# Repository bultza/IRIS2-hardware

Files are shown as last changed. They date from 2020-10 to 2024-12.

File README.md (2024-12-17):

# IRIS-2 Hardware
IRIS-2 is a 5 kg video and imaging instrument built by a group of friends (formed by enthusiastic amateur astronomers, engineers, and technicians). It follows the legacy of IRIS-1, which flew on Sunrise II in 2013. Its main goal is to provide imagery for communication and outreach, while also assisting in monitoring and improving the mechanical interfaces and PCS of the [Sunrise III observatory](https://www.mps.mpg.de/solar-physics/sunrise) from launch through landing and recovery. The cameras record 4K, 30 fps video for 2 hours during launch, 1 hour during landing, and 15 minutes at 120 fps during balloon release. At other times, they capture stills at 120-second intervals for time-lapse creation.

IRIS-2 was designed and assembled by:
* [Ramón García](https://github.com/rgalarcia/)
* [Miguel Angel Gomez](https://x.com/haploretro)
* [David Mayo](https://github.com/dmay0/)
* [Aitor Conde](https://github.com/bultza/)

To know more about the [Sunrise solar observatory](https://www.mps.mpg.de/solar-physics/sunrise)

## Design
IRIS-2 is build around 4 battery-less GOPRO Hero 4 cameras, with a central computer build with a MSP430 FRAM based microcontroller. The Instrument should be:
* Power independant
* Fully autonomous to detect launch and landing
* Able to make 4K videos
* Able to make a full timelapse of the flight of Sunrise over 7 day
* Able to stay in standby for days while drawing as less energy as possible.

## The hardware
The hardware has been designed using Altium Designer 21. The instrument has 2 boards (CPU and interface board), 4 cameras and a battery pack:
* The [IRIS2_PCB_CPU](https://github.com/bultza/IRIS2-hardware/tree/main/IRIS2_PCB_CPU): Where all the magic happens.
* The [IRIS2_PCB_Frontplate](https://github.com/bultza/IRIS2-hardware/tree/main/IRIS2_PCB_FrontPlate): a PCB to interface the instrument with the exterior world.
* 4 "GoPro HERO 4" cameras
* 4 [MewPro 2](https://mewpro.cc/en/product/mewpro-2/) interface boards to control the cameras
* 56 NiMH Eneloop AA cells, (8 in parallel, 7 in series)

<div align="center">
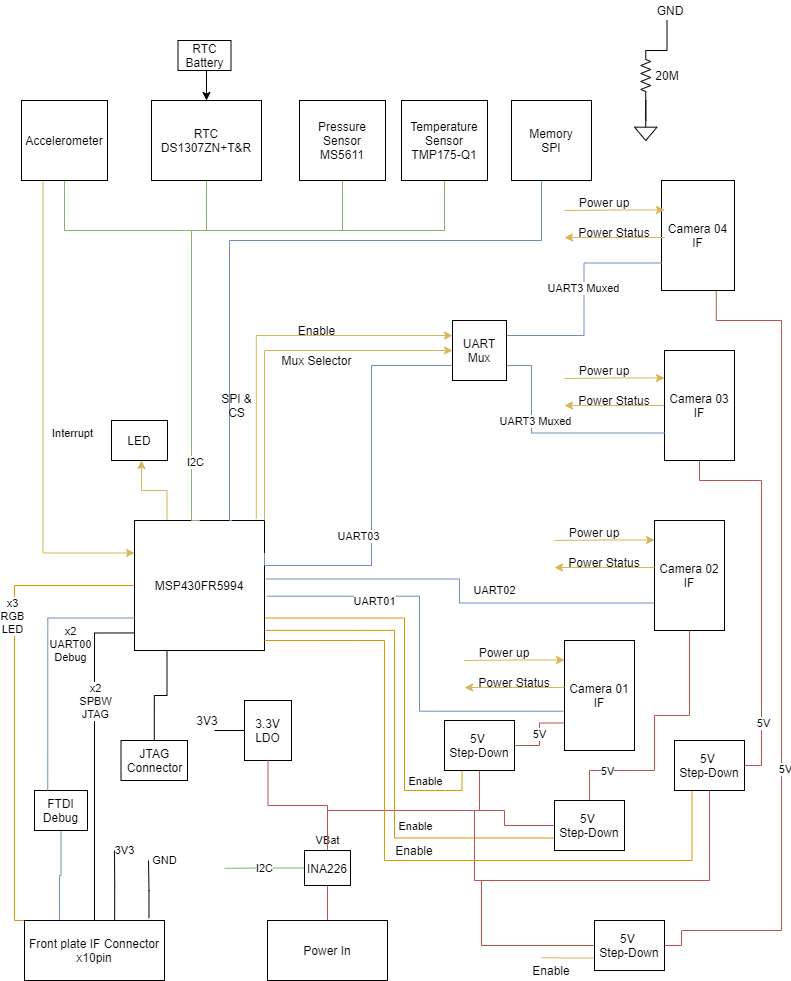
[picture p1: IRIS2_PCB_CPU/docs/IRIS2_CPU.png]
IRIS2 CPU Block Diagram

</div>

<div align="center">
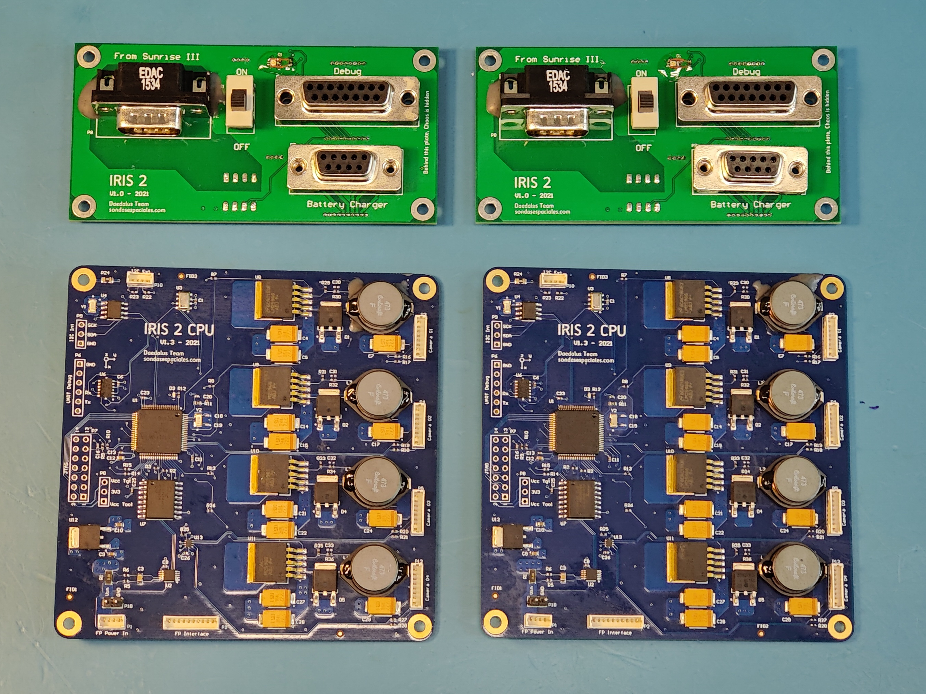
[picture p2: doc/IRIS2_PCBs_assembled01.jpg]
IRIS-2 PCBs from the top

</div>

<div align="center">
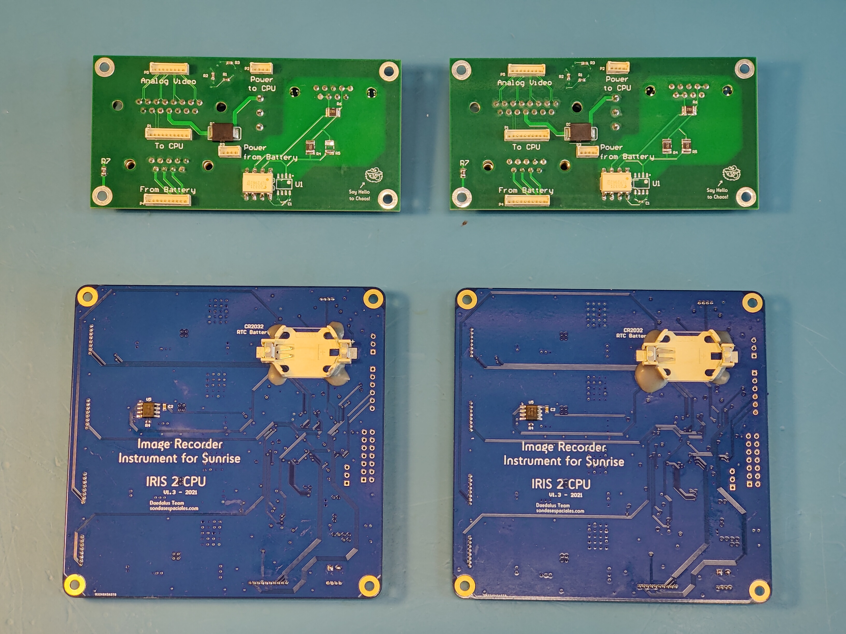
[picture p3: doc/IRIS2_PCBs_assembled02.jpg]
IRIS-2 PCBs from the bottom

</div>

## The budgets
IRIS-2 design tradeofs where very much affected by the output of the budgets. The full detail in the [IRIS2 Budget_DuringFlight.xlsx](https://github.com/bultza/IRIS2-hardware/blob/main/doc/IRIS2%20Budget_DuringFlight.xlsx) and it contains:
* Power Budget
* Data Budget
* Mass Budget

## Pictures
IRIS-2 in action:
<div align="center">
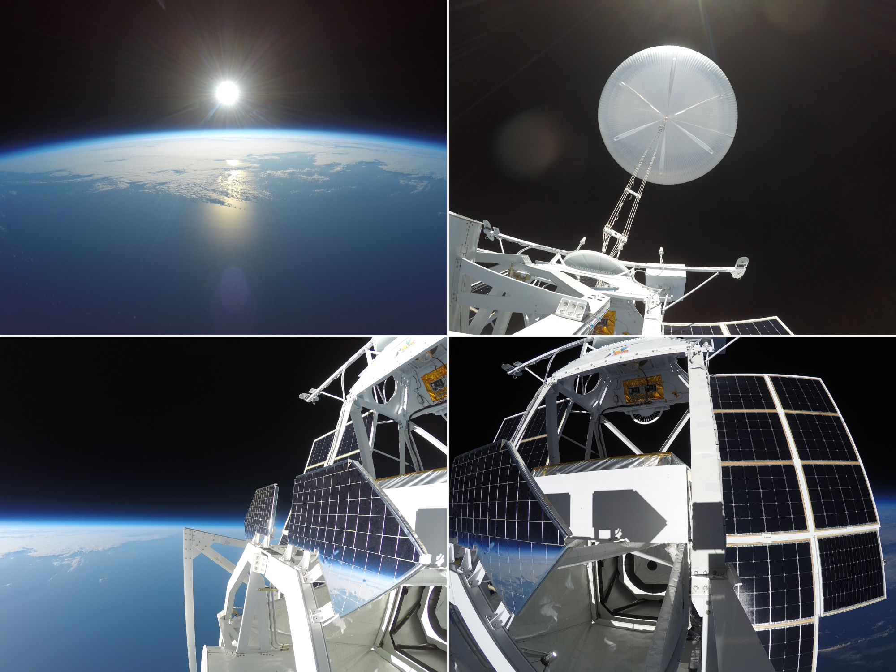
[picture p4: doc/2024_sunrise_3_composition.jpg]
Sunrise III image taken by IRIS2

</div>

IRIS-2 Mounted on Sunrise III
<div align="center">
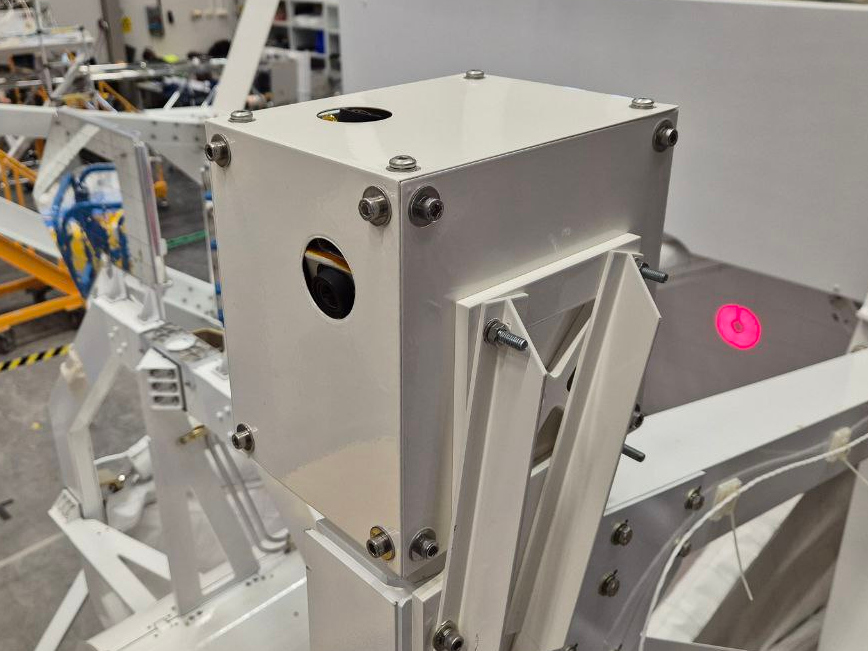
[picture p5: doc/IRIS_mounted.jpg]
IRIS-2 Mounted on Sunrise III

</div>

## Videos of the Flight
Here you can find a set of videos taken by the instrument, including the timelapses:
* [Main video covering the full mission](https://youtu.be/CKWAjiNBPxo)
* [The playlist with all the timelapses](https://www.youtube.com/watch?v=dQEWQV9Ofiw&list=PLlCuSjIHDIh0sF5nbLt4HJ0wI6yLDL5Xi)

## Flight Software
The software for this mission is at a different repository that can be found here: https://github.com/bultza/IRIS2-firmware-flight. It contains:
* The flight software
* The scripts to read and translate the Events to Human readable text
* The scripts to load the telemetry into a influx database for later usage on a Grafana dashboard 

## Authors
This was done using invaluable time from my friends. We all contributed to the success of this mission:
* [Ramón García](https://github.com/rgalarcia/)
* [Miguel Angel Gomez](https://x.com/haploretro)
* [David Mayo](https://github.com/dmay0/)
* [Aitor Conde](https://github.com/bultza/)

## License
This project is licensed under the CERN Open Hardware Licence Version 2 - Weakly Reciprocal (CERN-OHL-W). You can find the full text of the license in the [LICENSE](LICENSE.md) file in this repository or at the [CERN OHL website](https://ohwr.org/project/cernohl/wikis/home).

Please ensure that any use or modification of this project includes the following notice:
"Original design by [Daedalus Team/IRIS-2 Instrument]. Modifications must be shared under the same CERN-OHL-W license."

Under this license, you are free to use, modify, and distribute this hardware design. If you modify the design and distribute your changes, you must make those changes available under this same license.

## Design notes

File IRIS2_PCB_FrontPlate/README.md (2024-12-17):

# IRIS2 FrontPlate PCB
This is the IRIS2 FrontPlate PCB design for the IRIS2 instrument. It acts as the interface plate with the external world:
* With a general Switch to power on or off
* A debug port for debugging and configuration
* A charging port to extgernally charge the main battery
* A GPIO Port to interface Sunrise to have an external trigger for the start of the mission

The project was built using Altium Designer 2021 version.

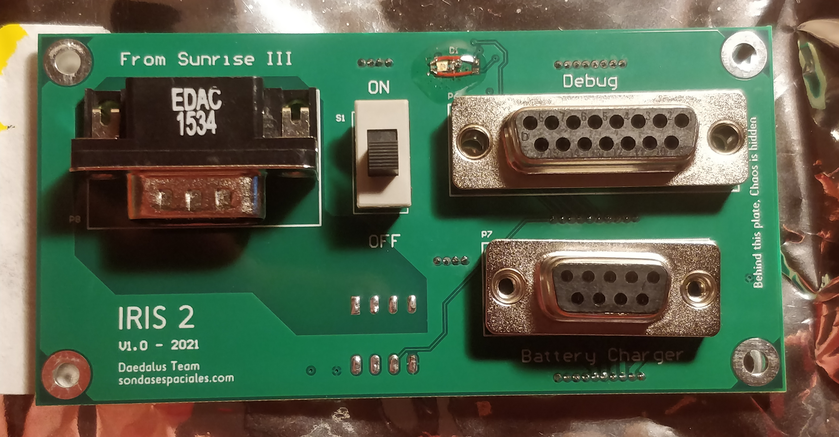
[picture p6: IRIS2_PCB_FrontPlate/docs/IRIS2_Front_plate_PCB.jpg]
IRIS-2 Front Plate from the top


## Documentation
Relevant documentation can be found on the docs folder including the datasheets of all the components:
* [Block Diagram](https://github.com/bultza/IRIS2-hardware/blob/main/IRIS2_PCB_FrontPlate/docs/IRIS2_FrontPlate.png)
* [Schematics PDF](https://github.com/bultza/IRIS2-hardware/blob/main/IRIS2_PCB_FrontPlate/docs/IRIS2_PCB_FrontPlate.pdf)
* [Pinouts](https://github.com/bultza/IRIS2-hardware/blob/main/IRIS2_PCB_FrontPlate/docs/IRIS2_pinouts.xlsx)
* [3D Step File](https://github.com/bultza/IRIS2-hardware/blob/main/IRIS2_PCB_FrontPlate/docs/IRIS2_PCB_FrontPlate_3D.step)

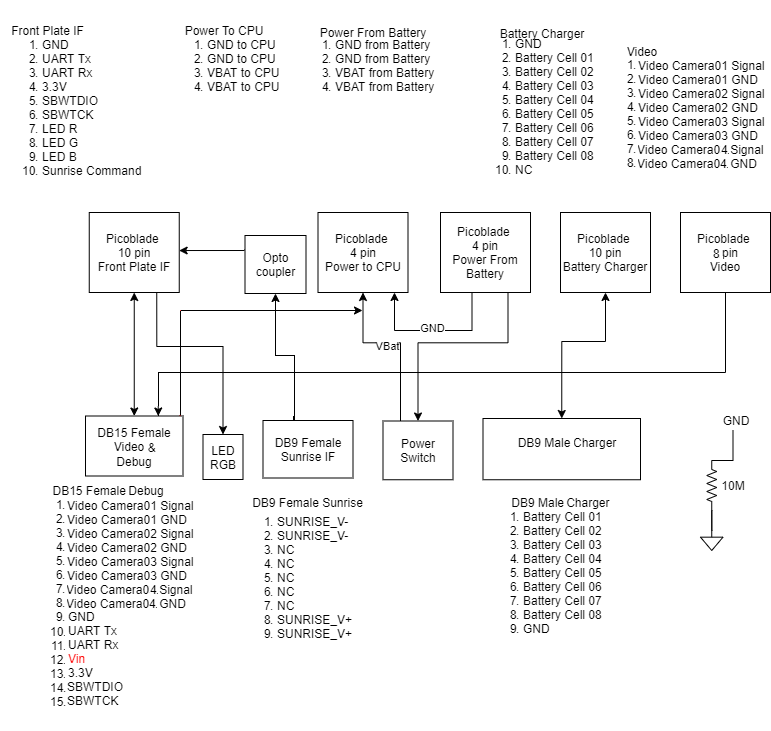
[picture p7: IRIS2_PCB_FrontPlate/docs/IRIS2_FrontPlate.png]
IRIS-2 Front Plate Block Diagram


## Authors
https://github.com/bultza/IRIS2-hardware/tree/main

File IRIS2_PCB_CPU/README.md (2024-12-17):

# IRIS2 CPU PCB
This is the IRIS2 CPU PCB design for the IRIS2 instrument that has flown twice, during the Summer 2022 and the Summer of 2024. The PCB Contains:
* A Central low power with flight heritage MCU: MSP430FR5994
* A pressure Sensors to measure the altitude of the instrument above the surface
* Four independent DC-DCs to power the GoPro Cameras
* A Current and voltage monitor
* A 3 axis accelerometer to detect Free-fall
* A NOR flash memory to save all the telemetry and event logs
* A RTC clock in order to be able to track down the telemetry

The project was built using Altium Designer 2021 version.

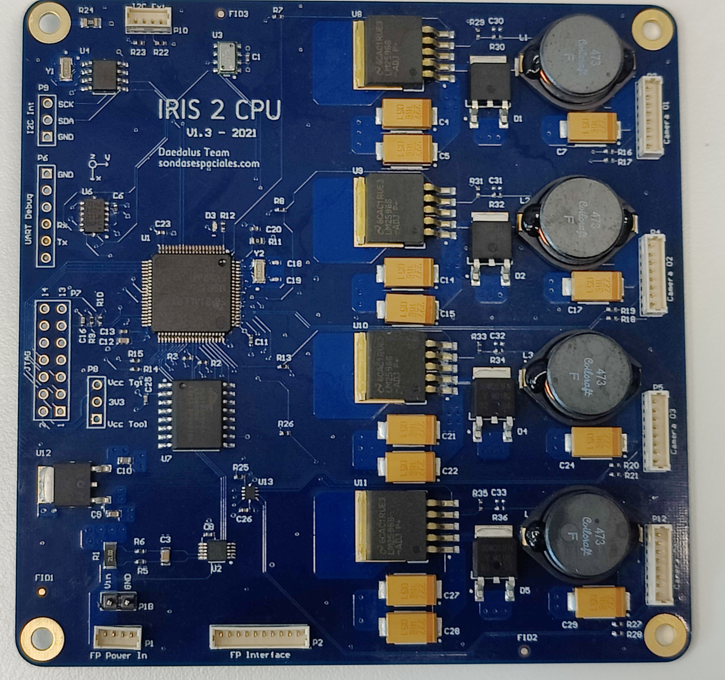
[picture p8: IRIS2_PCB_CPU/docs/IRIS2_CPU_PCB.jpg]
IRIS-2 CPU from the top


## Documentation
Relevant documentation can be found on the docs folder including the datasheets of all the components:
* [Block Diagram](https://github.com/bultza/IRIS2-hardware/blob/main/IRIS2_PCB_CPU/docs/IRIS2_CPU.png)
* [Schematics PDF](https://github.com/bultza/IRIS2-hardware/blob/main/IRIS2_PCB_CPU/docs/IRIS2_PCB_CPU_v1.3.pdf)
* [Pinouts](https://github.com/bultza/IRIS2-hardware/blob/main/IRIS2_PCB_CPU/docs/IRIS2_pinouts.xlsx)
* [3D Step File](https://github.com/bultza/IRIS2-hardware/blob/main/IRIS2_PCB_CPU/docs/20210401_IRIS2_PCB_CPU.step)
* [The User manual & Software](https://github.com/bultza/IRIS2-firmware-flight)

IRIS-2 CPU Block Diagram

## Authors
https://github.com/bultza/IRIS2-hardware/tree/main

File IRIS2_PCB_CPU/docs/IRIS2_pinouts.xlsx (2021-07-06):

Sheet: MCU
Pin | Multiplexed Peripherals | Used | Name | Comment
1 | P1.0/TA0.1/DMAE0/RTCCLK/A0/C0/VREF-/VeREF | P1.0 | DEBUG_LED | Debug led
2 | P1.1/TA0.2/TA1CLK/COUT/A1/C1/VREF+/VeREF+
3 | P1.2/TA1.1/TA0CLK/COUT/A2/C2
4 | P3.0/A12/C12
5 | P3.1/A13/C13
6 | P3.2/A14/C14
7 | P3.3/A15/C15
8 | P6.0/UCA3TXD/UCA3SIMO | UCA3TXD | UCA3TXD | UART Camera 03 TX
9 | P6.1/UCA3RXD/UCA3SOMI | UCA3RXD | UCA3RXD | UART Camera 03 RX
10 | P6.2/UCA3CLK
11 | P6.3/UCA3STE
12 | P4.7
13 | P7.0/UCB2SIMO/UCB2SDA | UCB2SDA | UCB2SDA | External I2C SDA for external sensors
14 | P7.1/UCB2SOMI/UCB2SCL | UCB2SCL | UCB2SCL | External I2C SCL for external sensors
15 | P8.0
16 | P1.3
17 | P1.4/TB0.1/UCA0STE/A4/C4
18 | P1.5/TB0.2/UCA0CLK/A5/C5
19 | DVSS2 | DVSS2 | GND | Power
20 | DVCC2 | DVCC2 | 3.3V | Power
21 | PJ.0/TDO/TB0OUTH/SMCLK/SRSCG1/C6 | TDO | TDO | JTAG
22 | PJ.1/TDI/TCLK/MCLK/SRSCG0/C7 | TDI | TDI | JTAG
23 | PJ.2/TMS/ACLK/SROSCOFF/C8 | TMS | TMS | JTAG
24 | PJ.3/TCK/SRCPUOFF/C9 | TCK | TCK | JTAG
25 | P7.2/UCB2CLK
26 | P7.3/UCB2STE/TA4.1
27 | P7.4/TA4.0/A16
28 | P7.5/A17 | P7.5 | POWERCAM01_BUTTON | Power Button Camera 01 (Output)
29 | P7.6/A18 | P7.6 | POWERCAM02_BUTTON | Power Button Camera 02 (Output)
30 | P7.7/A19 | P7.7 | POWERCAM03_BUTTON | Power Button Camera 03 (Output)
31 | P4.0/A8 | P4.0 | POWERCAM01_STATUS | Power from Camera 01 Status (Input)
32 | P4.1/A9 | P4.1 | POWERCAM02_STATUS | Power from Camera 02 Status (Input)
33 | P4.2/A10 | P4.2 | POWERCAM03_STATUS | Power from Camera 03 Status (Input)
34 | P4.3/A11
35 | P2.5/TB0.0/UCA1TXD/UCA1SIMO | UCA1TXD | UCA1TXD | UART Camera 01 TX
36 | P2.6/TB0.1/UCA1RXD/UCA1SOMI | UCA1RXD | UCA1RXD | UART Camera 01 RX
37 | TEST/SBWTCK | TEST | SBWTCK | SpyByWire TCK
38 | RST/NMI/SBWTDIO | RST | SBWTDIO | SpyByWire TDIO
39 | DVSS3 | DVSS3 | GND | Power
40 | DVCC3 | DVCC3 | 3.3V | Power
41 | P2.0/TB0.6/UCA0TXD/UCA0SIMO/TB0CLK/ACLK | UCA0TXD | UCA0TXD | UART Debug Tx
42 | P2.1/TB0.0/UCA0RXD/UCA0SOMI | UCA0RXD | UCA0RXD | UART Debug Rx
43 | P2.2/TB0.2/UCB0CLK | P2.2 | SUNRISE_CMD | Command from SunRise
44 | P8.1 | P8.1 | LED_R | LED Red
45 | P8.2 | P8.2 | LED_G | LED Green
46 | P8.3 | P8.3 | LED_B | LED Blue
47 | P3.4/TB0.3/SMCLK
48 | P3.5/TB0.4/COUT
49 | P3.6/TB0.5 | P3.6 | FLASH_CS2
50 | P3.7/TB0.6 | P3.7 | ACC_INT | Accelerometer Interrupt
51 | P1.6/TB0.3/UCB0SIMO/UCB0SDA/TA0.0 | UCB0SDA | UCB0SDA | I2C Bus SDA
52 | P1.7/TB0.4/UCB0SOMI/UCB0SCL/TA1.0 | UCB0SCL | UCB0SCL | I2C Bus SCK
53 | P5.0/UCB1SIMO/UCB1SDA | UCB1SIMO | UCB1SIMO | SPI Flash SIMO
54 | P5.1/UCB1SOMI/UCB1SCL | UCB1SOMI | UCB1SOMI | SPI Flash SOMI
55 | P5.2/UCB1CLK/TA4CLK | UCB1CLK | UCB1CLK | SPI Flash CLK
56 | P5.3/UCB1STE | P5.3 | FLASH_CS1 | SPI Flash CS
57 | P4.4/TB0.5 | P4.4 | 5VPOWER_EN_3 | Camera 3 5V Power Enable
58 | P4.5 | P4.5 | 5VPOWER_EN_2 | Camera 2 5V Power Enable
59 | P4.6 | P4.6 | 5VPOWER_EN_1 | Camera 1 5V Power Enable
60 | DVSS1 | DVSS1 | GND | Power
61 | DVCC1 | DVCC1 | 3.3V | Power
62 | P2.7 | P2.7 | 5VPOWER_EN_4 | Camera 4 5V Power Enable
63 | P2.3/TA0.0/UCA1STE/A6/C10 | P2.3 | UART_Mux_Enable | UART Camera 03 & 04 Mux Enable
64 | P2.4/TA1.0/UCA1CLK/A7/C11 | P2.4 | UART_Mux_Selection | UART Camera 03 & 04 Mux Switch
65 | P5.4/UCA2TXD/UCA2SIMO/TB0OUTH | UCA2TXD | UCA2TXD | UART Camera 02 TX
66 | P5.5/UCA2RXD/UCA2SOMI/ACLK | UCA2RXD | UCA2RXD | UART Camera 02 RX
67 | P5.6/UCA2CLK/TA4.0/SMCLK | P5.6 | POWERCAM04_BUTTON | Power Button Camera 04 (Output)
68 | P5.7/UCA2STE/TA4.1/MCLK | P5.7 | POWERCAM04_STATUS | Power from Camera 04 Status (Input)
69 | P6.4/UCB3SIMO/UCB3SDA
70 | P6.5/UCB3SOMI/UCB3SCL
71 | P6.6/UCB3CLK
72 | P6.7/UCB3STE
73 | AVSS3 | AVSS3 | GND | Power
74 | PJ.6/HFXIN
75 | PJ.7/HFXOUT
76 | AVSS2 | AVSS2 | GND | Power
77 | PJ.4/LFXIN | LFXIN | LFXIN | Xtal 32kHz for millis()
78 | PJ.5/LFXOUT | LFXOUT | LFXOUT | Xtal 32kHz for millis()
79 | AVSS1 | AVSS1 | GND | Power
80 | AVCC1 | AVCC1 | 3.3V | Power

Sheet: Front Plate PCB
Front Plate IF Picoblade |  |  | Power to CPU Picoblade |  |  | Battery Charger Picoblade |  |  | Video Picoblade
Pin | Name | Direction | Pin | Name | Direction | Pin | Name | Direction | Pin | Name | Direction
1 | GND | Bidirectional | 1 | GND | Out | 1 | GND | Bidirectional | 1 | Video Camera 01 Signal | Input
2 | UART Tx | In | 2 | GND | Out | 2 | Battery Cell 01 | Bidirectional | 2 | Video Camera 01 GND | Input
3 | UART Rx | Out | 3 | VBAT | Out | 3 | Battery Cell 02 | Bidirectional | 3 | Video Camera 02 Signal | Input
4 | 3.3V | Bidirectional | 4 | VBAT | Out | 4 | Battery Cell 03 | Bidirectional | 4 | Video Camera 02 GND | Input
5 | SBWTDIO | Bidirectional |  |  |  | 5 | Battery Cell 04 | Bidirectional | 5 | Video Camera 03 Signal | Input
6 | SBWTCK | Bidirectional | Power From Battery Picoblade |  |  | 6 | Battery Cell 05 | Bidirectional | 6 | Video Camera 03 GND | Input
7 | LED R | In | Pin | Name | Direction | 7 | Battery Cell 06 | Bidirectional | 7 | Video Camera 04 Signal | Input
8 | LED G | In | 1 | GND | In | 8 | Battery Cell 07 | Bidirectional | 8 | Video Camera 04 GND | Input
9 | LED B | In | 2 | GND | In | 9 | Battery Cell 08 | Bidirectional
10 | Sunrise Command | Out | 3 | VBAT | In | 10 | NC
 |  |  | 4 | VBAT | In
DB15 Female Debug + Video |  |  | DB9 Male Sunrise |  |  | DB9 Female Charger
Pin | Name | Direction | Pin | Name | Direction | Pin | Name | Direction
1 | Video Camera 01 Signal | Output | 1 | SUNRISE_V+ |  | 1 | Battery Cell 01 | Bidirectional
2 | Video Camera 01 GND | Output | 2 | SUNRISE_V+ |  | 2 | Battery Cell 02 | Bidirectional
3 | Video Camera 02 Signal | Output | 3 | NC |  | 3 | Battery Cell 03 | Bidirectional
4 | Video Camera 02 GND | Output | 4 | NC |  | 4 | Battery Cell 04 | Bidirectional
5 | Video Camera 03 Signal | Output | 5 | NC |  | 5 | Battery Cell 05 | Bidirectional
6 | Video Camera 03 GND | Output | 6 | NC |  | 6 | Battery Cell 06 | Bidirectional
7 | Video Camera 04 Signal | Output | 7 | NC |  | 7 | Battery Cell 07 | Bidirectional
8 | Video Camera 04 GND | Output | 8 | SUNRISE_V- |  | 8 | Battery Cell 08 | Bidirectional
9 | GND | Bidirectional | 9 | SUNRISE_V- |  | 9 | GND | Bidirectional
10 | UART Tx | Out
11 | UART Rx | In
12 | Vin | Bidirectional
13 | 3.3V | Bidirectional
14 | SBWTDIO | Bidirectional
15 | SBWTCK | Bidirectional

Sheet: CPU PCB
Front Plate IF Picoblade |  |  | Camera 01 IF |  |  | UART Debug
Pin | Name | Direction | Pin | Name | Direction | Pin | Name | Direction
1 | GND | Bidirectional | 1 | GND | Out | 1 | GND | Bidirectional
2 | UART Tx | Out | 2 | GND | Out | 2 | NC
3 | UART Rx | In | 3 | 3.9V | Out | 3 | NC
4 | 3.3V | Bidirectional | 4 | 3.9V | Out | 4 | TXD | In | Rx from MCU
5 | SBWTDIO | Bidirectional | 5 | UART Tx | Out | 5 | RXD | Out | Tx from MCU
6 | SBWTCK | Bidirectional | 6 | UART Rx | In | 6 | NC
7 | LED R | Out | 7 | Power On | Out
8 | LED G | Out | 8 | Power Status | In
9 | LED B | Out
10 | Sunrise Command | In
Front Plate Power |  |  | Camera 02 IF |  |  | JTAG MSP430
Pin | Name | Direction | Pin | Name | Direction | Pin | Name | Direction
1 | GND | In | 1 | GND | Out | 1 | TDO/TDI
2 | GND | In | 2 | GND | Out | 2 | Vcc
3 | VBAT | In | 3 | 3.9V | Out | 3 | TDI/Vpp
4 | VBAT | In | 4 | 3.9V | Out | 4 | Vcc Ext
 |  |  | 5 | UART Tx | Out | 5 | TMS
 |  |  | 6 | UART Rx | In | 6 | NC
 |  |  | 7 | Power On | Out | 7 | TCK
 |  |  | 8 | Power Status | In | 8 | TEST/Vpp
 |  |  |  |  |  | 9 | GND
 |  |  |  |  |  | 10 | NC
 |  |  |  |  |  | 11 | RST
 |  |  |  |  |  | 12 | NC
 |  |  | Camera 03 IF |  |  | 13 | NC
 |  |  | Pin | Name | Direction | 14 | NC
 |  |  | 1 | GND | Out
 |  |  | 2 | GND | Out
 |  |  | 3 | 3.9V | Out
 |  |  | 4 | 3.9V | Out
 |  |  | 5 | UART Tx | Out
 |  |  | 6 | UART Rx | In
 |  |  | 7 | Power On | Out
 |  |  | 8 | Power Status | In

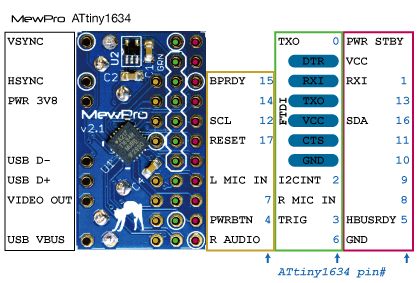
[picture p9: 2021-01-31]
IRIS2_PCB_CPU/docs/datasheets/GoPro_MewPro2_Pinout.jpg

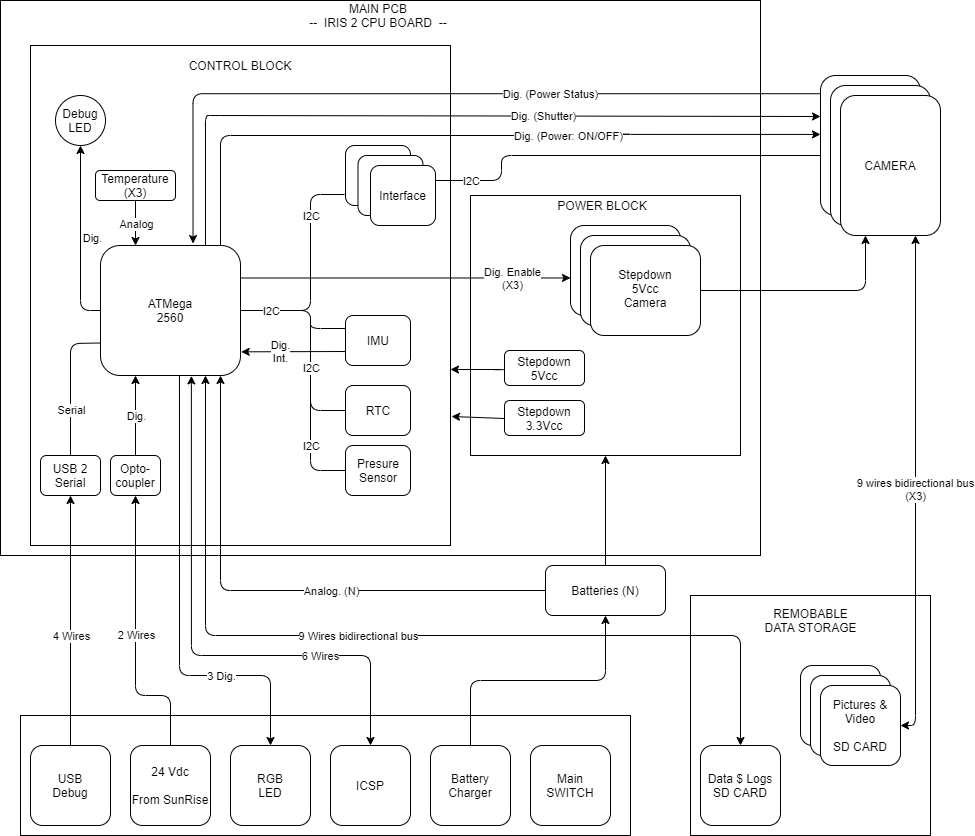
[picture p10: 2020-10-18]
IRIS2/01-Design/schematics/IRIS_2-Block_Diagram.png

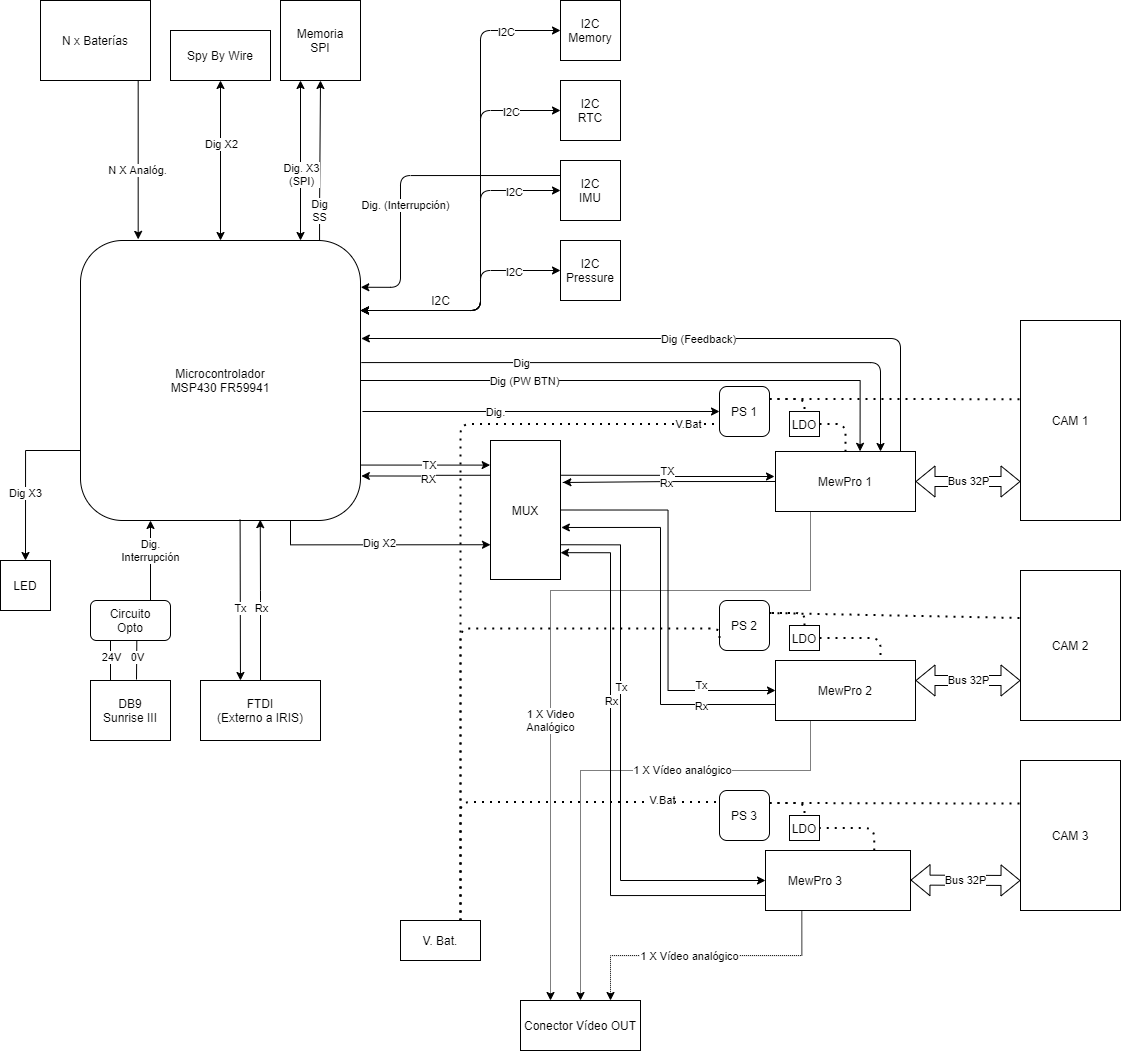
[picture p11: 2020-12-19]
IRIS2/01-Design/schematics/IRIS_2 - CPU PCB Block_Diagram.png

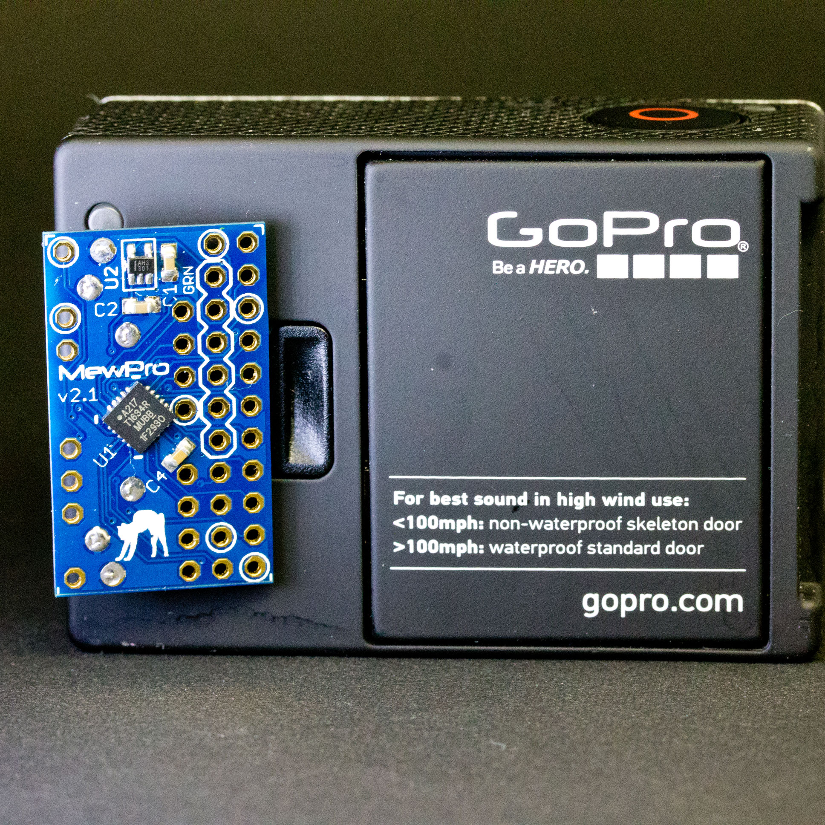
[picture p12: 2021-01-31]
IRIS2_PCB_CPU/docs/datasheets/GoPro_MewPro2.jpg

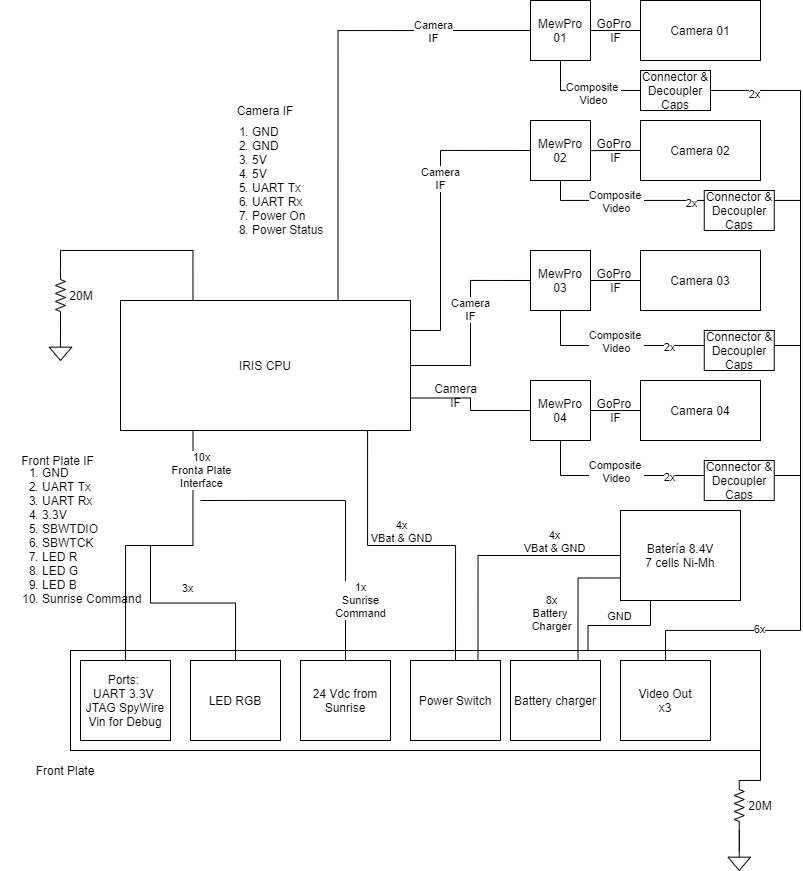
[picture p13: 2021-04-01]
IRIS2_PCB_CPU/docs/IRIS2.png

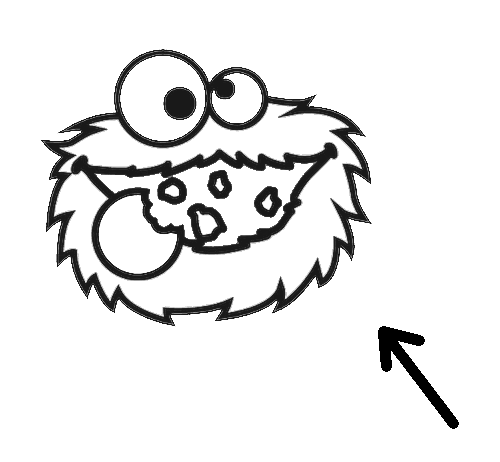
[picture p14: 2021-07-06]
IRIS2_PCB_FrontPlate/docs/datasheets/coockieMonster.png

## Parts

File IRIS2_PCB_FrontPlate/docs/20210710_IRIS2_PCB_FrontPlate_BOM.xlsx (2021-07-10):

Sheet: IRIS2_PCB_FrontPlate_BOM
From? | Designator | Footprint | Quantity | Manufacturer | Reference | Description | Comment | Number Boards | Total to buy | Cost Unity | Cost total | URL
Front Plate | C1 | 0402 | 1 | Murata | GCM155R71C104KA55D | Capacitor |  | 3 | 3 | 0.085 | 0.255 | https://www.mouser.es/ProductDetail/Murata-Electronics/GCM155R71C104KA55D?qs=aEuGZpxfbxVTPYRtXT4ecg%3D%3D
Front Plate | D1 | PCBComponent_1 | 1 | Wurth Elektronik | 156125M173000 | RGB LED |  | 3 | 3 | 1.02 | 3.06 | https://www.mouser.es/ProductDetail/Wurth-Elektronik/156125M173000
Front Plate | D2 | SMC | 1 | Comchip Technology | CDBC520-G | Default Diode |  | 3 | 3 | 0.542 | 1.626 | https://www.mouser.es/ProductDetail/Comchip-Technology/CDBC520-G
Front Plate | P1, P4 | 53047-1010 | 2 | Molex | 53047-1010 | Header, 10-Pin | NO STOCK | 3 | 6 | 0.483 | 2.898 | https://www.mouser.es/ProductDetail/Molex/53047-1010
Front Plate | P2, P3 | 53047-0410 | 2 | Molex | 053047-0410 | Header, 4-Pin |  | 3 | 6 | 0.254 | 1.524 | https://www.mouser.es/ProductDetail/Molex/53047-0410?qs=DcEdecHHM4i8IPBxVAuJtg%3D%3D
Front Plate | P5 | 53047-0810 | 1 | Molex | 053047-0810 | Header, 8-Pin |  | 3 | 3 | 0.398 | 1.194 | https://www.mouser.es/ProductDetail/Molex/53047-0810?qs=yVuyZxZd%2FtwixHNjj7O2xA%3D%3D
Front Plate | P6 | DB15 Female 191-015-213 | 1 | NorComp | 191-015-223R001 | Header, 15-Pin |  | 3 | 3 | 5.18 | 15.54 | https://www.mouser.es/ProductDetail/NorComp/191-015-223R001
Front Plate | P7 | DB9 Female 191-009-213 | 1 | NorComp | 191-009-113L551 | Header, 9-Pin |  | 3 | 3 | 1.81 | 5.43 | https://www.mouser.es/ProductDetail/NorComp/191-009-113L551
Front Plate | P8 | DB9 Male 621-009-668-032 | 1 | EDAC | 621-009-668-032 | Header, 9-Pin |  | 3 | 3 | 5.95 | 17.85 | https://www.mouser.es/ProductDetail/EDAC/621-009-668-032
Front Plate | R4, R5, R6 | C1210_M | 3 | TE Connectivity, [NoValue] | CRGP1210F2K7, [NoValue] | Resistor |  | 3 | 9 | 0.381 | 3.429 | https://www.mouser.es/ProductDetail/TE-Connectivity-Holsworthy/CRGP1210F2K7
Front Plate | R7 | 6-0805_N | 1 | KOA | RK73B2ATTD206J | Resistor |  | 3 | 3 | 0.111 | 0.333 | https://www.mouser.es/ProductDetail/KOA-Speer/RK73B2ATTD206J
Front Plate | S1 | CS12ANW03 | 1 | NKK Switches | CS12ANW03 | Switch |  | 3 | 3 | 1.48 | 4.44 | https://www.mouser.es/ProductDetail/NKK-Switches/CS12ANW03
Front Plate | U1 | SOIC127P600X135-8N | 1 | Toshiba | TLP2962(TP1,F) | Optocoupler |  | 3 | 3 | 1.19 | 3.57 | https://www.mouser.es/ProductDetail/Toshiba/TLP2962TP1F
Front Plate | U1 | SOIC127P600X135-8N | 1 | Toshiba | TLP2962 | Optocoupler | Might not be in stock | 3 | 3 | 1.09 | 3.27 | https://www.mouser.es/ProductDetail/Toshiba/TLP2962F?qs=7hO1d5R1VguFweIXXg87CA%3D%3D
CPU Board | Y1, Y2 |  | 2 |  | ABS07W-32.768KHZ-D-2-T | Crystal |  | 5 | 10 | 1.3 | 13 | https://www.mouser.es/ProductDetail/ABRACON/ABS07W-32768KHZ-D-2-T
CPU Board | U6 |  | 1 |  | ADXL345BCCZ | Accelerometer |  | 5 | 5 | 5.28 | 26.4 | https://www.mouser.es/ProductDetail/Analog-Devices/ADXL345BCCZ?qs=WIvQP4zGanhoa7YOkGtvEg%3D%3D
CPU Board | U13 |  | 1 |  | PI3USB221AZUAEX | Mux | NO STOCK | 5 | 5 | 0.61 | 3.05 | https://www.mouser.es/ProductDetail/Diodes-Incorporated/PI3USB221AZUAEX
CPU Board | U2 |  | 1 |  | INA226AQDGSRQ1 | INA | NO STOCK | 5 | 5 | 3.54 | 17.7 | https://www.mouser.es/ProductDetail/Texas-Instruments/INA226AQDGSRQ1
Harness |  | single cable | 82 | Molex | 214921-1114 |  |  | 3 | 246 | 0.49 | 120.54 | https://www.mouser.es/ProductDetail/Molex/79758-0014
Harness |  | 10 pin | 3 | Molex | 51021-1000 |  |  | 3 | 9 | 0.313 | 2.817 | https://www.mouser.es/ProductDetail/Molex/51021-1000?qs=sGAEpiMZZMvlX3nhDDO4AH5liFrgzHxR2nUyLeJuVJs%3D
Harness |  | 4 pin | 3 | Molex | 51021-0400 |  | NO STOCK | 3 | 9 | 0.229 | 2.061 | https://www.mouser.es/ProductDetail/Molex/51021-0400
Harness |  | 8 pin | 2 | Molex | 51021-0800 |  |  | 3 | 6 | 0.356 | 2.136 | https://www.mouser.es/ProductDetail/Molex/51021-0800?qs=zi95yC3thwEO31wDz4TQLA%3D%3D

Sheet: Cable Calculations
Connector | From | To | How many | contacts | ends in? | Duplicate? | Total | Connectors
CPU-gopro | Cpu | Gopro | 4 | 8 | solder | 1 | 32 | 10 pin | 3
CPU-Vbat | CPU | Front Plate | 1 | 4 | picoblade | 2 | 8 | 4 pin | 3
CPU-FrontPlate | CPU | Front Plate | 1 | 10 | picoblade | 2 | 20 | 8 pin | 2
FrontPlate-Power | Front Plate | Battery | 1 | 4 | solder | 1 | 4
FrontPlate-Bat | Front Plate | Battery | 1 | 10 | solder | 1 | 10
FrontPlate-Video | Front Plate | Gopros | 1 | 8 | solder | 1 | 8
 |  |  |  |  |  | Total | 82

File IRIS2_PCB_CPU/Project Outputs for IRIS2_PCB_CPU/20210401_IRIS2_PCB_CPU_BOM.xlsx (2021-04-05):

Designator | Quantity | Manufacturer | Reference | Footprint | Type | Description
C1, C6, C8, C11, C13, C20, C23, C25, C26 | 9 | Murata | GCM155R71C104KA55D | 0402 | SMD | 16V,Capacitor
C2, C10, C12 | 3 | Murata | GRT188R61A106ME13D | 1608[0603] | SMD | 10V,Capacitor
C3 | 1 | Murata | GCJ21BR71H104KA01L | 6-0805_L | SMD | 50V,Capacitor
C4, C5, C7, C14, C15, C17, C21, C22, C24, C27, C28, C29 | 12 | Kemet | T491D227M016AT | 2917 [7343 Metric] | SMD | Cap Pol2,Polarized Capacitor (Axial)
C9 | 1 | Murata | GRT188R61H105ME13D | 1608[0603] | SMD | Cap,Capacitor
C16 | 1 | Murata | GRM1557U1A202JA01D | 0402 | SMD | 50V,Capacitor
C18, C19 | 2 | Murata | GCQ1555C1H220GB01D | 0402 | SMD | Cap,Capacitor
D1, D2, D4, D5 | 4 | Vishay | VS-30WQ03FN | VS-30WQ03FN | SMD | VS-30WQ03FN Diode,VS-30WQ03FN Diode
D3 | 1 | ROHM Semiconductor | SMLP13EC8TT86 | 0402-A | SMD | Debug LED,Typical RED, GREEN, YELLOW, AMBER GaAs LED
L1, L2, L3, L4 | 4 | Coilcraft | DO5022P-473MLB | DO5022P-473MLB | SMD | Inductor,Inductor
P1, P10 | 2 | Molex | 0530470410 | 53047-0410 | THD | Header 4,Header, 4-Pin
P2 | 1 | Molex | 530471010 | 530471010 | THD | Header 10,Header, 10-Pin
P3, P4, P5, P12 | 4 | Molex | 0530470810 | 0530470810 | THD | Header 8,Header, 8-Pin
P11 | 1 | Renata | SMTU2032-LF | SMTU2032-LF | SMD | CR2032 Battery Holder,CR2032 Battery Holder
R1 | 1 | ROHM Semiconductor | PMR18EZPFV2L00 | INDC3216 | SMD | Res1,Resistor
R2, R3, R22, R23 | 4 | Panasonic | ERJ-2RKF4751X | 0402 | SMD | Res1,Resistor
R4, R10 | 2 | Panasonic | ERJ-2GEJ333X | 0402 | SMD | Res1,Resistor
R5, R6 | 2 | Panasonic | ERJ2RKD10R0X | 0402 | SMD | Res1,Resistor
R7, R8, R9, R13, R25, R26 | 6 | Panasonic | ERJ-2RKF4752X | 0402 | SMD | Res1,Resistor
R11 | 1 | Panasonic | ERJ-3GEY0R00V | J1-0603 | SMD | Res1,Resistor
R12, R14, R15, R16, R17, R18, R19, R20, R21, R27, R28 | 11 | Panasonic | ERJ-2RKF1371X | 0402 | SMD | Res1,Resistor
R24 | 1 | KOA | RK73B2ATTD206J | 6-0805_N | SMD | Res1,Resistor
U1 | 1 | Texas Instruments | MSP430FR5994IPNR | MSP430FR5994IPN | SMD | MSP430FR5994,MSP430FR5994, 80 pin MSP430 FRAM
U2 | 1 | Texas Instruments | INA226AQDGSRQ1 | INA226-Q1 | SMD | INA226-Q1 Power Monitor,Texas Instruments INA226-Q1 I2C temperature sensor INA226AQDGSRQ1
U3 | 1 | measurement specialties | MS561101BA03-50 | MS5611-01BA01 | SMD | MS5611-01BA01,MS5611-01BA01 Barometric Pressure Sensor
U4 | 1 | Maxim Integrated | DS1338Z-33+ | DS1338Z-33+ | SMD | RTC DS1338Z-33+,RTC I2C DS1338Z-33+ SOIC-8
U5 | 1 | Texas Instruments | TMP175AIDR | TMP75C-Q1 SOIC | SMD | TMP75C-Q1,TMP75C-Q1
U6 | 1 | Analog Devices | ADXL345-EP | ADXL345-EP | SMD | ADXL345-EP,ADXL345-EP I2C Accelerometer
U7 | 1 | Cypress | S70FL01GSAGMFV010 | SPIFlash_S70FL01GSAGMFV010 | SMD | S70FL01GS,S70FL01GS SPI NOR Flash
U8, U9, U10, U11 | 4 | Texas Instruments | LM2596S-5.0/NOPB | DPAK170P1435X457-6N | SMD | 5V Buck converter,LM2596S-5.0/NOPB 5V Buck converter
U12 | 1 | ROHM Semiconductor | BD433M5FP-CE2 | BD433M5FP-CE2 | SMD | BD433M5FP-CE2,BD433M5FP-CE2 LDO 3.3V 500mV
U13 | 1 | Diodes Incorporated | PI3USB221AZWEX | PI3USB221AZWEX | SMD | PI3USB221AZWEX,PI3USB221AZWEX Multiplexer
Y1, Y2 | 2 | ECS | ECS-.327-9-34R-TR | XTAL_ECS-.327-9-34R-TR | SMD | XTAL,Crystal Oscillator

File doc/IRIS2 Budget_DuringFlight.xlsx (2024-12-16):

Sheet: Budgets
 |  |  | Sunrise Mirror | Horizon + Telescope | Balloon | Sunside
Mission Configuration |  |  | Camera 1 | Camera 2 | Camera 3 | Camera 4 |  |  | Camera 1 | Sunrise Mirror
Mission Duration | 6.5 | days | 6.5 | 6.5 | 6.5 | 1 | days |  | Camera 2 | Horizon + Telescope
Launch recording duration | 2 | hours | 2 | 2 | 1 | 1 | h | 8.5 | Camera 3 | Sunside
Landing recording duration | 1 | hours | 0.5 | 1 | 0.5 | 0.5 | h |  | Camera 4 | Balloon
Timelapse periodicity | 120 | s | Batteries full date | Launch Date
Number of Cameras | 4 | # | 2022-04-26 | 2022-07-10
Launch Standby | 2 | days |  |  |  |  |  | GoPro Power
 |  |  |  | Batery NiMH |  |  |  |  | Voltage | W | Current | Cable derating
Battery Configuration |  |  |  | Current(mAh) | 2500 | mAh |  | Switched On | 3.92 | 1.5 | 0.3826530612 | 19.13%
In Series | 7 | # |  | Voltage | 1.2 | V |  | Taking picture | 3.92 | 1.78 | 0.4540816327 | 22.70%
In Parallel | 8 | # |  | Weight | 30 | gr |  | Taking video | 3.92 | 4 | 1.020408163 | 51.02%
Total Batteries | 56 | # |  | Energy | 3 | Watts/h |  | All Cameras On | 8 | 6 | 0.75 | 37.50%
Diode Fordward Voltage | 0.4 | V |  | Specific Energy | 0.1 | W/gr |  | All Cameras Recording | 8 | 16 | 2 | 100.00%
Pack Voltage | 8 | V |  | Specific Energy | 100 | W/Kg
Amp/hour | 20 | Ah |  | Dimension x | 14.5 | mm |  | GoPro Data Size |  |  | FOV | https://community.gopro.com/t5/es/Informaci-243-n-del-campo-de-visi-243-n-FOV-de-la-HERO4/ta-p/390417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
Wh | 160 | Wh |  | Dimension y | 14.5 | mm |  | Video Size | 8.212531328 | MB/s | Users guide | https://gopro.com/content/dam/help/hero4-black/music-bundle-manuals/UM_H4Black-Music_ENG_REVB_WEB.pdf
Weight | 1.68 | Kg |  | Dimension z | 51 | mm |  | Picture Size | 3.084 | MB | File size in JPG | https://toolstud.io/photo/filesize.php?imagewidth=4096&imageheight=3072
 |  |  |  |  |  |  |  | SDCard Size | 128 | GB | Video size | https://havecamerawilltravel.com/gopro/memory-card-size-gopro-hero4/
Camera Regulators |  |  |  |  |  |  |  | Picture Duration | 11.8 | s | Max capacity | https://images-eu.ssl-images-amazon.com/images/I/81FNp9Q5YZS.pdf
Current comsuption | 15 | mA |  |  |  |  |  | Picture Wh | 0.005834444444 | Wh
Efficiency | 90.00% | % |  |  | 4320 |  |  | Pic per day | 720 | #
 |  |  |  | 0.024 | 86400 |  |  | Time On | 8496 | s | 16000
 |  |  |  |  | 20 |  |  | Wh per day | 4.2008 | Wh/day | 1948.242188
 |  |  |  |  | 65536 |  |  |  |  |  | 0.5411783854
 |  | Standby for Launch |  |  | Launch |  |  | Landing |  |  | Timelapse
Device | Voltage (V) | Time (hours) | Current (mA) | Energy (Wh) | Time (hours) | Current (mA) | Energy (Wh) | Time (hours) | Current (mA) | Energy (Wh) | Time (hours) | Current (mA) | Energy (Wh)
IRIS2 CPU | 8 | 48 | 3 | 1.152 | 2 | 3 | 0.048 | 1 | 3 | 0.024 | 156 | 3 | 3.744
Camera 1 | 8 | 0 | 0 | 0 | 2 | 500 | 8 | 0.5 | 500 | 2 | 15.34 | 222.5 | 27.3052
Regulator Cam 1 | 8 | 0 | 0 | 0 | 2 | 15 | 0.24 | 0.5 | 15 | 0.06 | 15.34 | 15 | 1.8408
Regulator Cam 1 inefficiency | 8 | 0 | 0 | 0 | 2 | 50 | 0.8 | 0.5 | 50 | 0.2 | 15.34 | 22.25 | 2.73052
Camera 2 | 8 | 0 | 0 | 0 | 2 | 500 | 8 | 1 | 500 | 4 | 15.34 | 222.5 | 27.3052
Regulator Cam 2 | 8 | 0 | 0 | 0 | 2 | 15 | 0.24 | 1 | 15 | 0.12 | 15.34 | 15 | 1.8408
Regulator Cam 2 inefficiency | 8 | 0 | 0 | 0 | 2 | 50 | 0.8 | 1 | 50 | 0.4 | 15.34 | 22.25 | 2.73052
Camera 3 | 8 | 0 | 0 | 0 | 1 | 500 | 4 | 0.5 | 500 | 2 | 15.34 | 222.5 | 27.3052
Regulator Cam 3 | 8 | 0 | 0 | 0 | 1 | 15 | 0.12 | 0.5 | 15 | 0.06 | 15.34 | 15 | 1.8408
Regulator Cam 3 inefficiency | 8 | 0 | 0 | 0 | 1 | 50 | 0.4 | 0.5 | 50 | 0.2 | 15.34 | 22.25 | 2.73052
Camera 4 | 8 | 0 | 0 | 0 | 1 | 500 | 4 | 0.5 | 500 | 2 | 2.36 | 222.5 | 4.2008
Regulator Cam 4 | 8 | 0 | 0 | 0 | 1 | 15 | 0.12 | 0.5 | 15 | 0.06 | 2.36 | 15 | 0.2832
Regulator Cam 4 inefficiency | 8 | 0 | 0 | 0 | 1 | 50 | 0.4 | 0.5 | 50 | 0.2 | 2.36 | 22.25 | 0.42008
 |  |  | Total | 1.152 | Wh | Total | 27.168 | Wh | Total | 11.324 | Wh | Total | 104.27764 | Wh
 |  |  | Battery % | 0.72% |  | Battery % | 16.98% |  | Battery % | 7.08% |  | Battery % | 65.17%
Total Power Consuption |  |  |  | Data Budget
Launch Standby | 1.152 | Wh |  |  | Camera 01 | Camera 02 | Camera 03 | Camera 04
Launch | 27.168 | Wh |  | N Pictures | 4680 | 4680 | 4680 | 720 |  | 14760
Timelapse | 104.27764 | Wh |  | Size Pic(MB) | 14433.12 | 14433.12 | 14433.12 | 2220.48
Landing | 11.324 | Wh |  | Video Minutes | 150 | 180 | 90 | 90 |  | 510 | 8.5
Margin 10% | 0 | Wh |  | Size Vid(MB) | 73912.78195 | 88695.33835 | 44347.66917 | 44347.66917
Total Battery | 143.92164 | Wh |  | Total Size (GB) | 86.27529488 | 100.7113851 | 57.40311443 | 45.47670818
Total Battery % | 89.95% |  |  | Total % | 67.40% | 78.68% | 44.85% | 35.53%
 |  |  |  | Timelapse Budget
 |  |  |  |  | Camera 01 | Camera 02 | Camera 03 | Camera 04
 |  |  |  | N Pictures | 4680 | 4680 | 4680 | 720
 |  |  |  | 60 FPS | 78 | 78 | 78 | 12 | s
 |  |  |  | 30 FPS | 156 | 156 | 156 | 24 | s

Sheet: Mass Budget
MASS BUDGET
Element | Unitary/m/m^2 mass | Number/m/m^2 | Total mass [kg]
Bars | 0.7 | 1.95 | 1.365
Panels | 2.2 | 0.2 | 0.44
Junctions | 0.008 | 28 | 0.224
Bolts | 0.005 | 56 | 0.28
CPU PCB | 0.1 | 1 | 0.1
FP PCB | 0.1 | 1 | 0.1
Harness | 0.4 | 1 | 0.4
Batteries | 0.04 | 64 | 2.56
Bat. holders | 0.0218 | 8 | 0.1744
GoPros | 0.074 | 4 | 0.296
MewPros |  | 4
 |  | Total IRIS 2 Mass: | 5.9394

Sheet: GoPro HERO4 Silver Data
Power consumption data from GoPro HERO4 Silver (real tests) 8.4 V
 | Min (mA) | Typical (mA) | Max (mA)
Standby | 220 | 230 | 250
Taking picture |  | 275
Recording video | 320 | 350 | 390
1635289871 | 129 | 823 | 96 | 2 | hours
1635289873 | 240 | 816 | 207 | 0.05
1635289875 | 147 | 822 | 114 | 0.2 | A
1635289877 | 212 | 818 | 179 | 8.4 | V
1635289878 | 283 | 813 | 250 | 1.68 | Wh
1635289880 | 319 | 811 | 286 | 3.36 | Wh
1635289882 | 329 | 810 | 296
1635289884 | 310 | 811 | 277
1635289886 | 355 | 808 | 322
1635289888 | 308 | 811 | 275
1635289890 | 140 | 823 | 107
19 | 2.772 | 89.66 | 2.409
 |  | 8.150909091 | 0.219
 | W | 1.785049091

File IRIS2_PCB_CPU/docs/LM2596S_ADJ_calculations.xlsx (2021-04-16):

R1 | 1370 | ohm
Vout desired | 4 | V
Vref | 1.23 | V
R2 | 3085.284553 | ohm
R2 Selected | 3000 | ohm | RCC04022K20FKED
Vout real | 3.923430657 | V
 | 0.03923430657
 | 3.962664964
 | 3.88419635

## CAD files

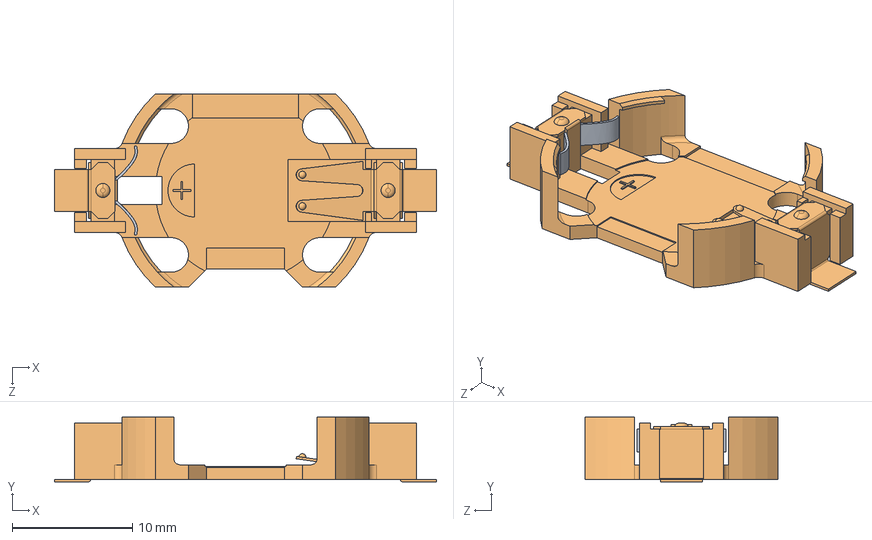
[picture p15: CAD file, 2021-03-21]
IRIS2_PCB_CPU/docs/datasheets/BATT HOLDER_SMTU2032-LF.STEP
31.8 x 5.40 x 16.1 mm

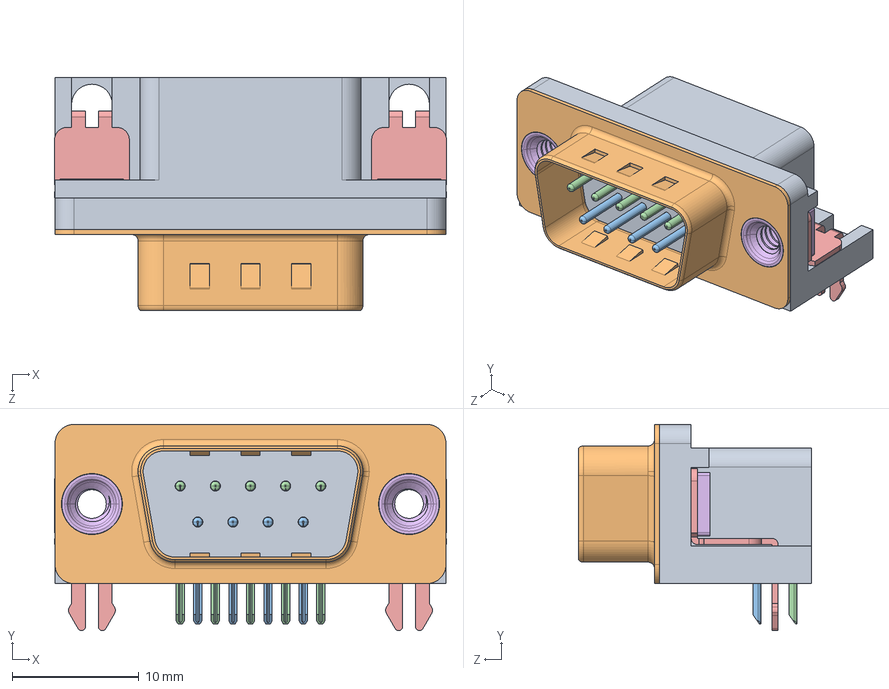
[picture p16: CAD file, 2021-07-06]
IRIS2_PCB_FrontPlate/docs/datasheets/621-009-668-032 - EDAC D-Sub Connector.STEP
30.9 x 16.2 x 18.4 mm
621 Housing_9 Socket
621 Shell_9 Socket
621 Contact Bottom x 4
621 Contact Top x 5
621 2 Prong Board Lock x 2
621 4-40 Threaded Rivet x 2

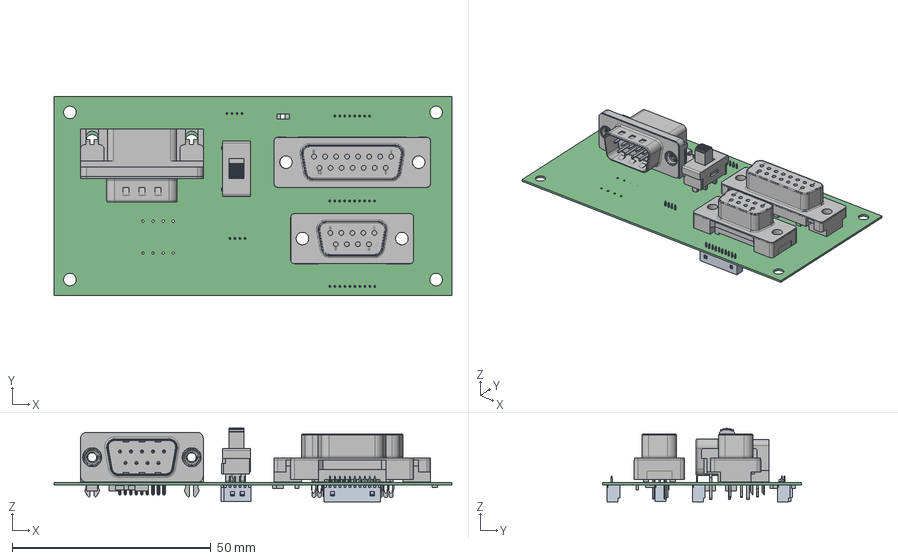
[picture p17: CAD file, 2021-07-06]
IRIS2_PCB_FrontPlate/docs/IRIS2_PCB_FrontPlate_3D.step
100.0 x 50.0 x 18.5 mm
Extruded x 11
621_Housing_9_Socket
621_Shell_9_Socket
621_Contact_Bottom x 4
621_Contact_Top x 5
621_2_Prong_Board_Lock x 2
621_4-40_Threaded_Rivet x 2
191-015-223_RGB8421504
191-009-213_RGB8421504
_CS12ANW03-body
_CS12ANW03-top
_CS12ANW03-term
_CS12ANW03-slide

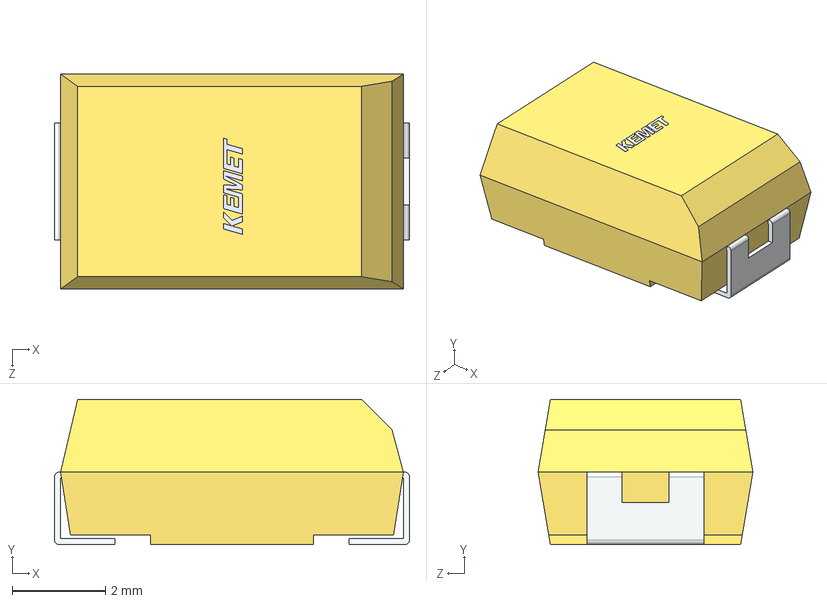
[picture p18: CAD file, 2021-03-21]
IRIS2_PCB_CPU/docs/datasheets/T491D227M016AT.step
7.60 x 3.11 x 4.60 mm

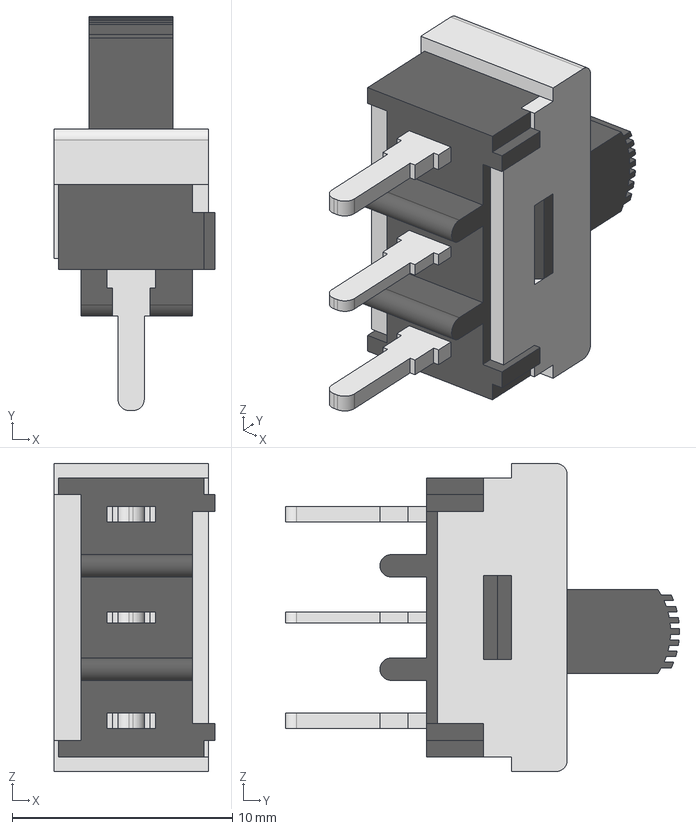
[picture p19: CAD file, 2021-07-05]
IRIS2_PCB_FrontPlate/docs/datasheets/CS12ANW03.stp
7.32 x 17.9 x 14.0 mm
_CS12ANW03-body
_CS12ANW03-top
_CS12ANW03-term
_CS12ANW03-slide

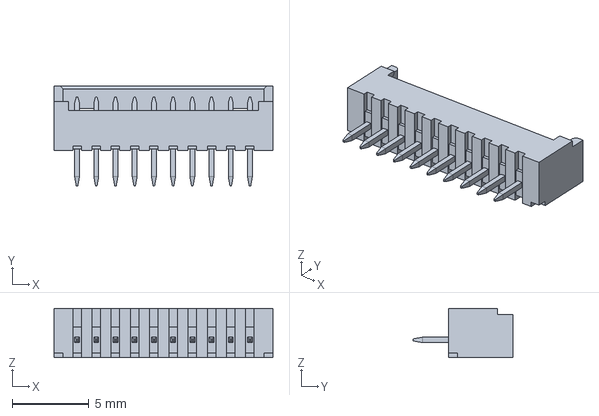
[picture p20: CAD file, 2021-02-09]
IRIS2_PCB_CPU/docs/datasheets/Molex_530471010.stp
14.2 x 6.50 x 3.20 mm

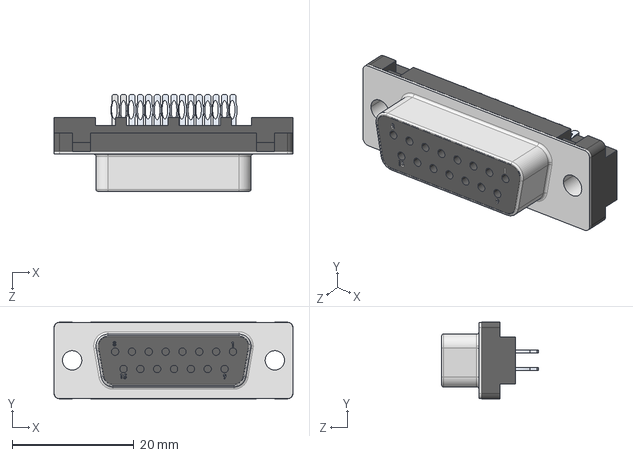
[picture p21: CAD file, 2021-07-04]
IRIS2_PCB_FrontPlate/docs/datasheets/191-015-223.STEP
39.3 x 12.6 x 16.0 mm

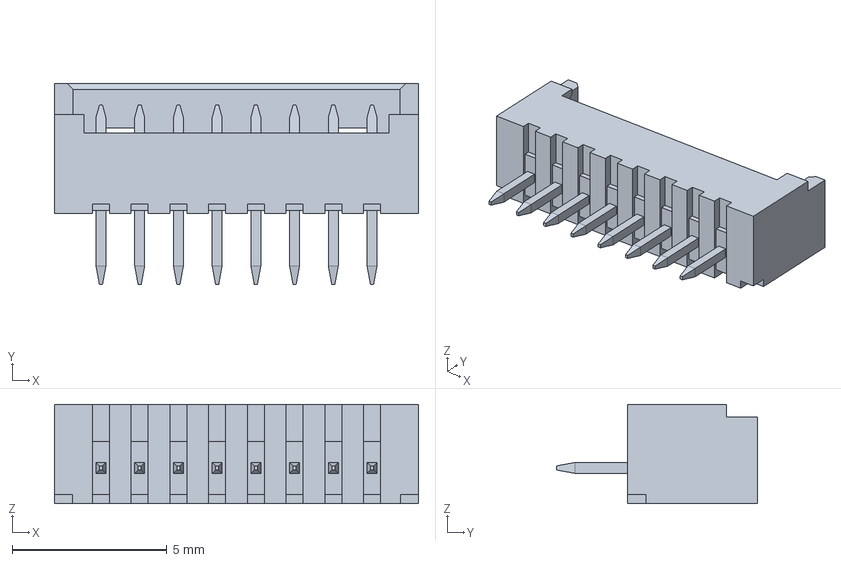
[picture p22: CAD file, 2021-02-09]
IRIS2_PCB_CPU/docs/datasheets/Molex_530470810.stp
11.8 x 6.50 x 3.20 mm

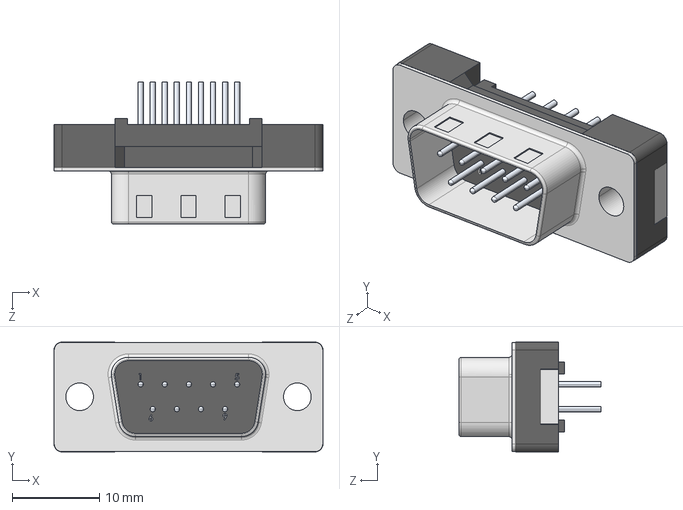
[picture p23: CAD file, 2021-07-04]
IRIS2_PCB_FrontPlate/docs/datasheets/191-009-113.STEP
30.9 x 12.6 x 16.3 mm

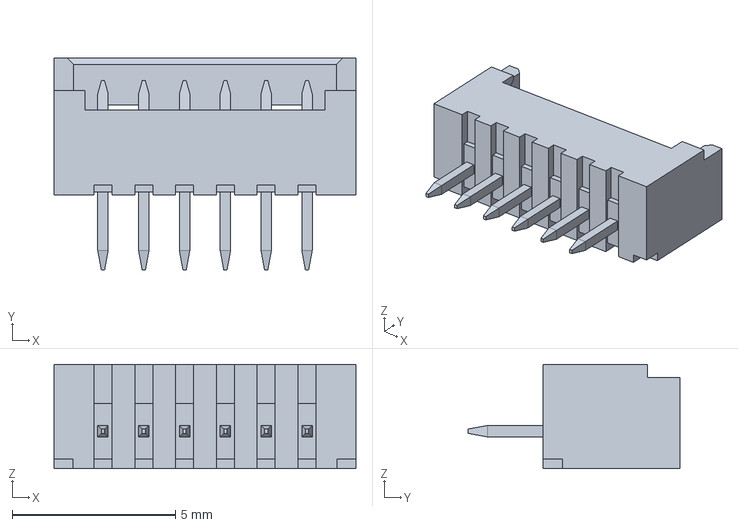
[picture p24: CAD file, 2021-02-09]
IRIS2_PCB_CPU/docs/datasheets/Molex_530470610.stp
9.25 x 6.50 x 3.20 mm

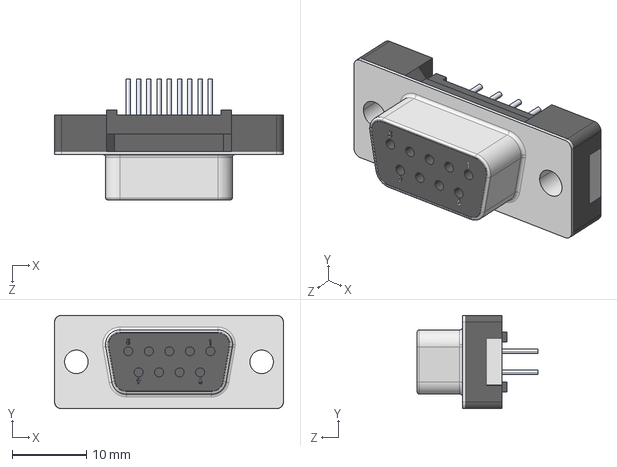
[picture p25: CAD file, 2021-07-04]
IRIS2_PCB_FrontPlate/docs/datasheets/191-009-213.STEP
30.9 x 12.6 x 16.4 mm

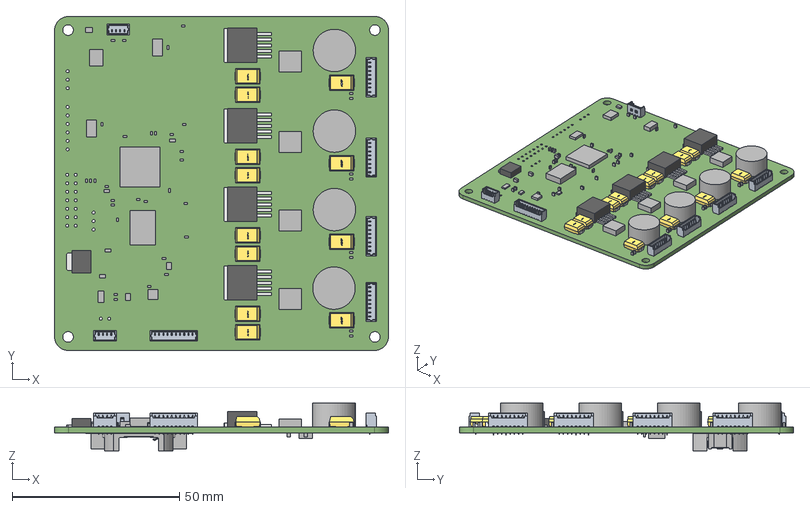
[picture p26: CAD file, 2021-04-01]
IRIS2_PCB_CPU/docs/20210401_IRIS2_PCB_CPU.step
99.9 x 99.9 x 14.2 mm
Extruded x 88
T491D227M016AT x 12
BATT_HOLDER_SMTU2032-LF_RGB8421504

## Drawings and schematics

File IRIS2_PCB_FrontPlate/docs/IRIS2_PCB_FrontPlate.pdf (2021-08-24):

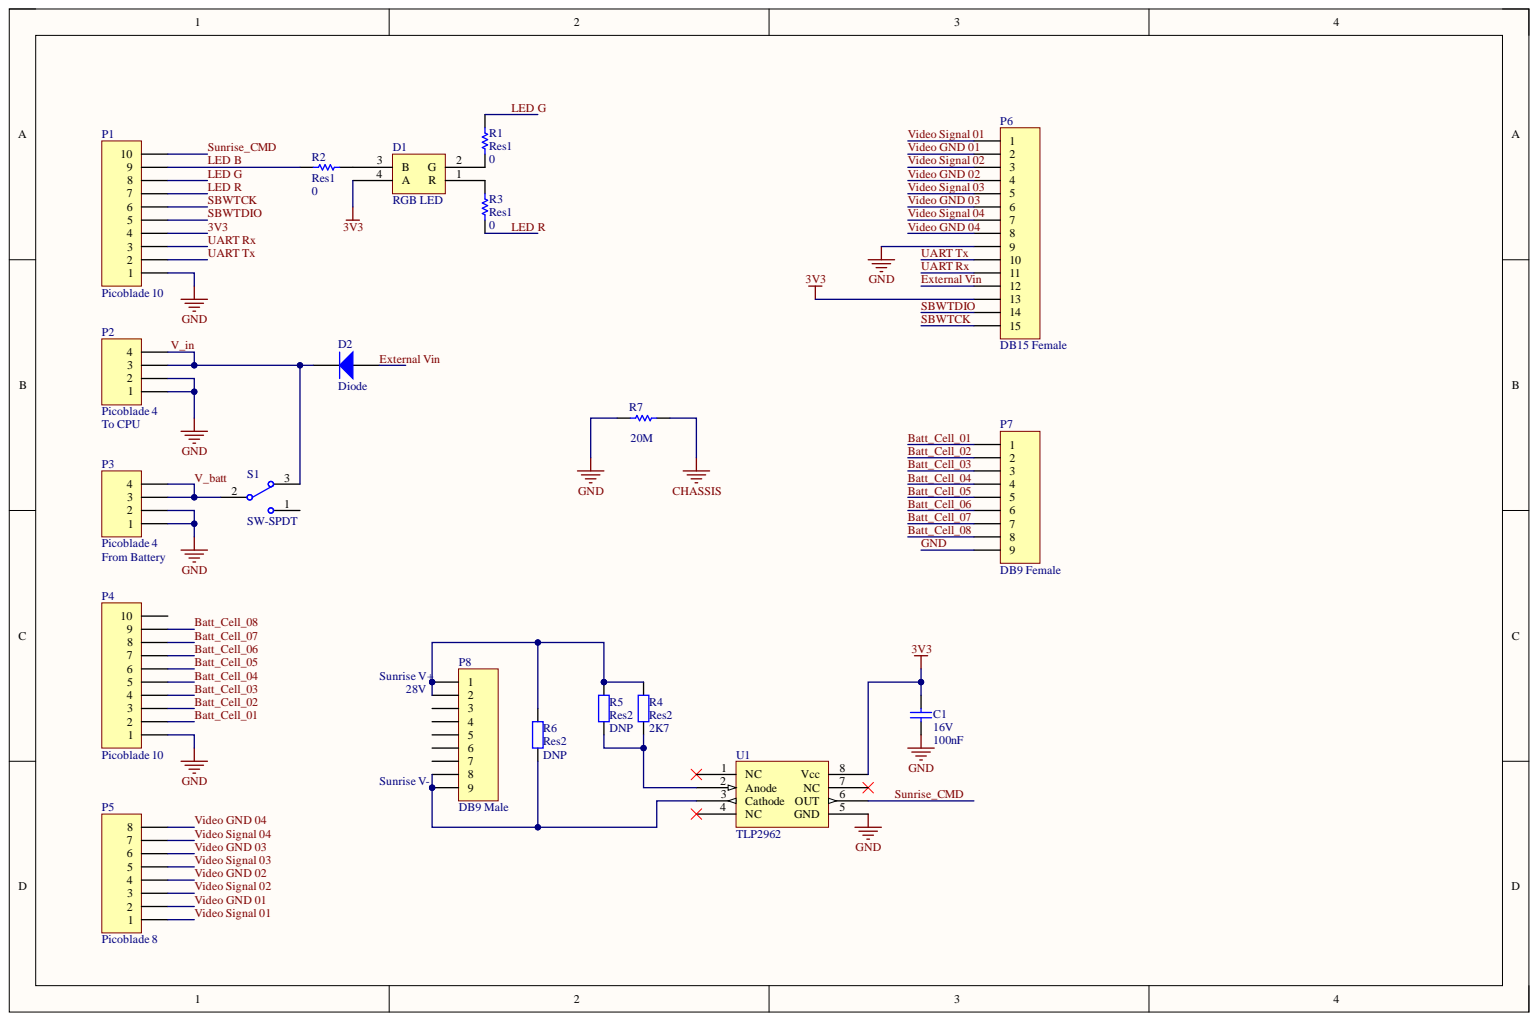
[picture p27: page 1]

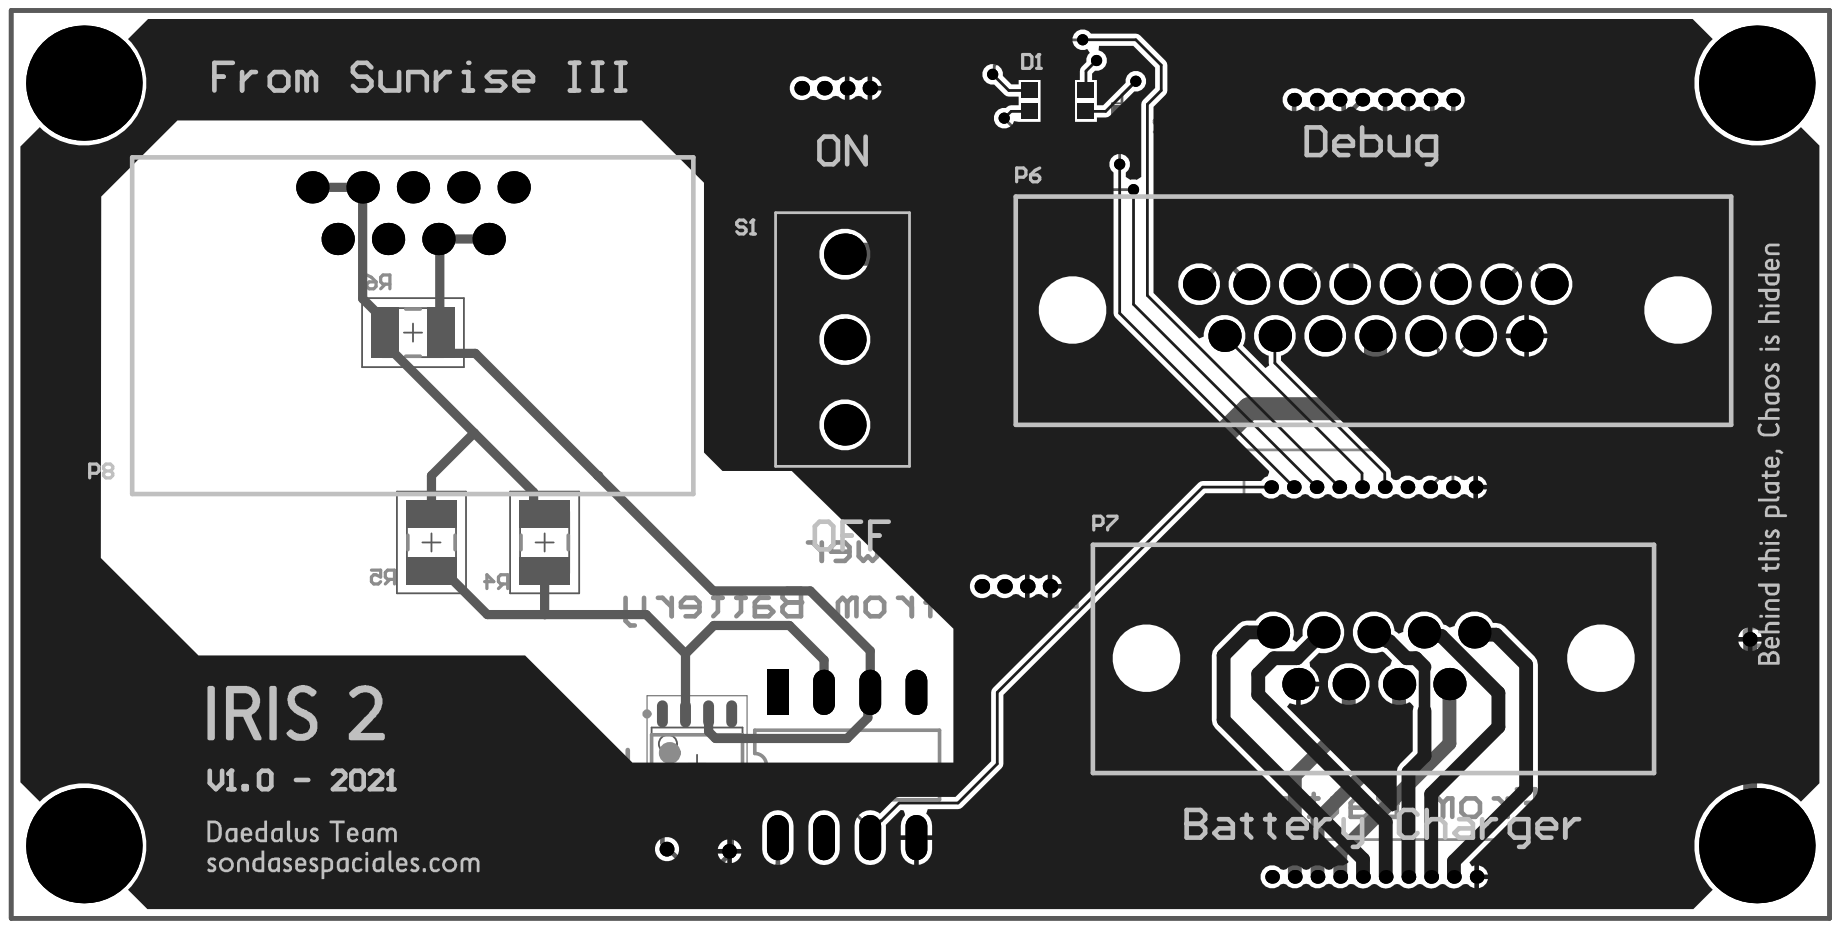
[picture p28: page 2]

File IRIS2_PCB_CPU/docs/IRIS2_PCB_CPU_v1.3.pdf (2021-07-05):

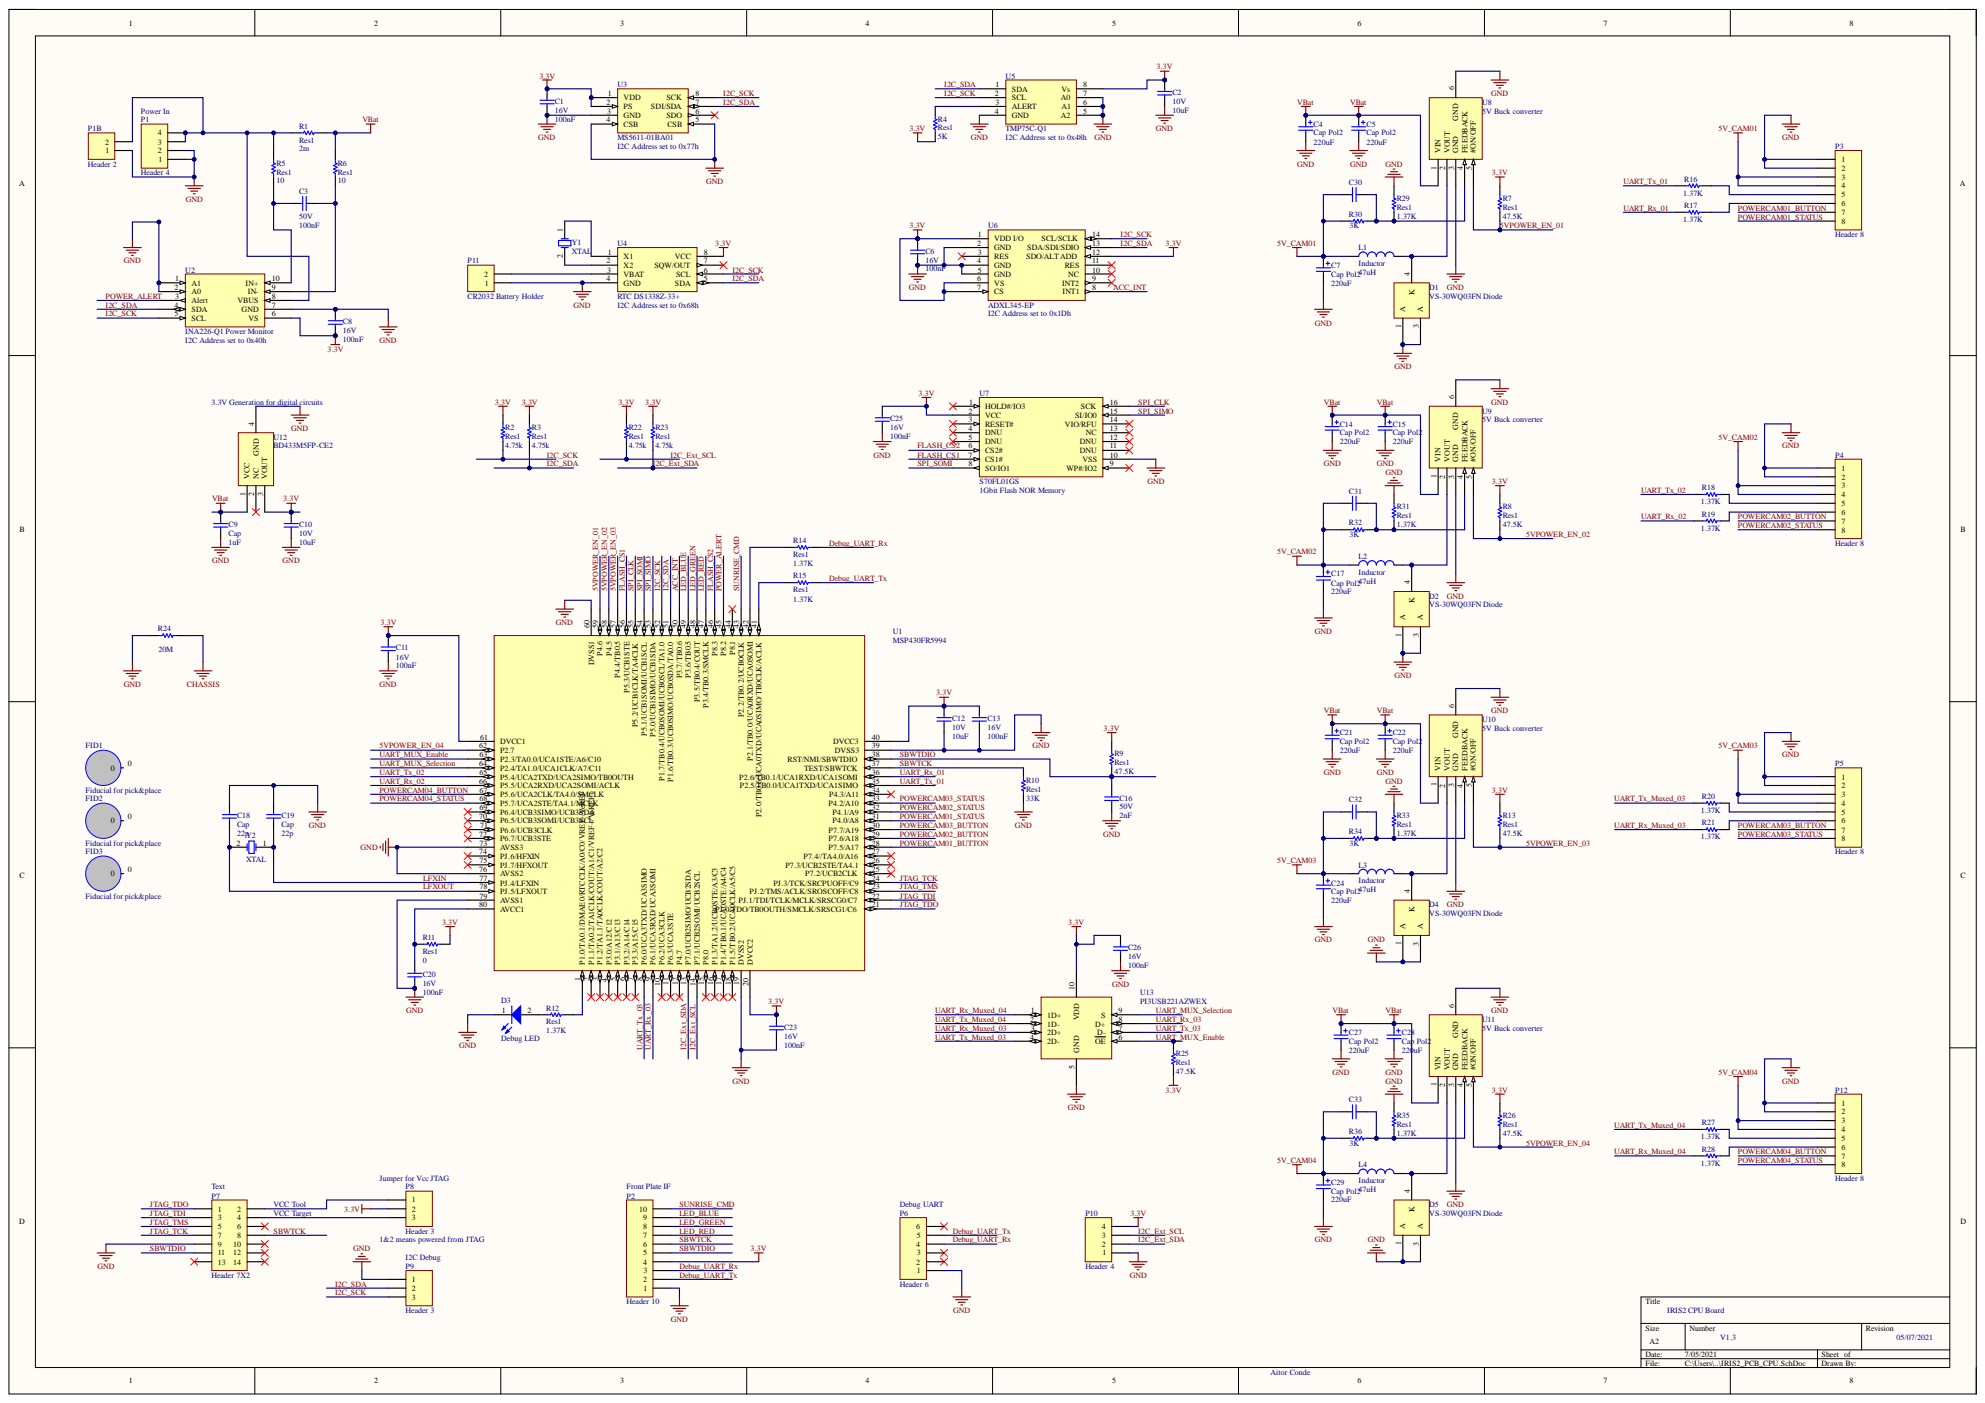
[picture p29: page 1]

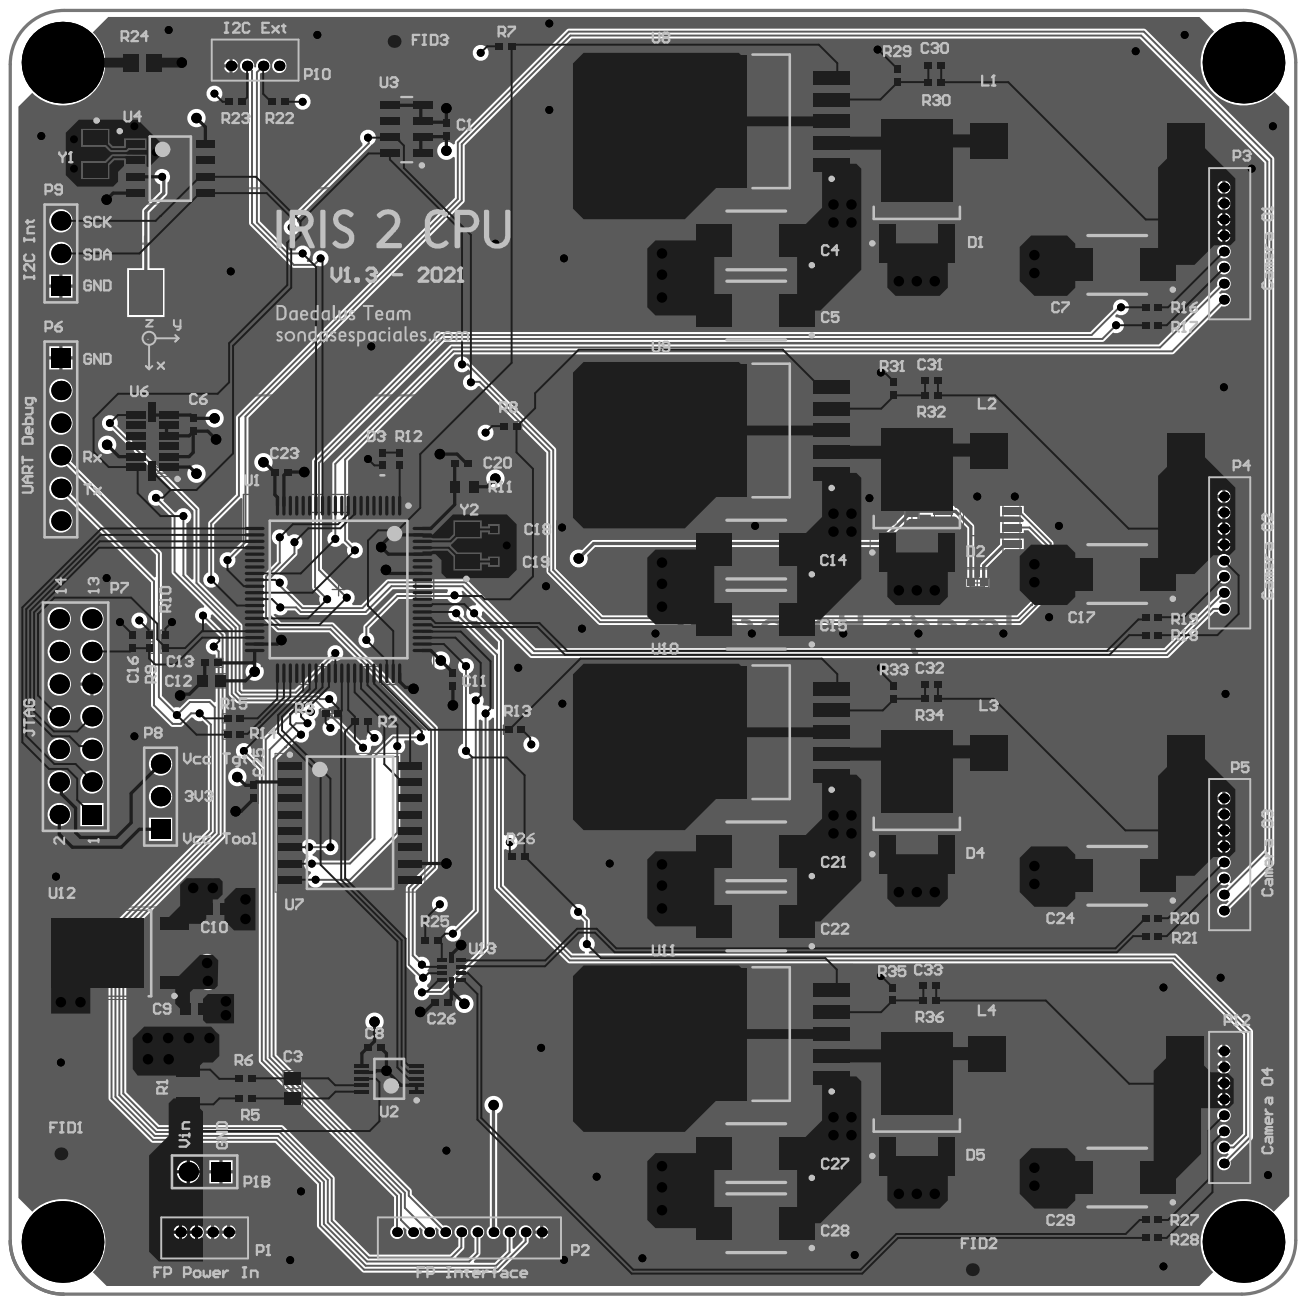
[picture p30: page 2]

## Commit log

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2020-12-17 Ingeniería inversa mewpro - gropro - I2C
    Examen de algunas de las tramas I2C entre el mewpro y la gopro
    [Cambios de modo.ods, Encender y apagar gopro.ods]
2020-12-19 Añadido Reset y señal SS de SPI
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2021-01-31 Adding the first version of the schematics of IRIS2 globally and also the CPU Adding an excel file with all the pinouts on the electronics Deleting old files Adding datasheets for electronics we are 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
    [IRIS2_pinouts.xlsx]
2021-01-31 CPU schematics actualizado con el mismo MCU del launchpad y quitado el mux Movidos los pines en el pinout del MCU para hacerlos más compatibles con el launchpad ;)
    [IRIS2_pinouts.xlsx]
2021-01-31 Updating the pinout document with the missing parts
    [IRIS2_pinouts.xlsx]
2021-01-31 Starting the Altium project for both IRIS2_CPU_PCB and IRIS2_FrontPlate_PCB In the CPU added the INA, the MCU and some connectors.
    [IRIS2_PCB_CPU.PrjPcb, IRIS2_PCB_CPU.SchDoc, IRIS2_PCB_FrontPlate.PrjPcb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]
2021-02-01 List of electronic devices
    Añado la lista de los componentes electrónicos que estaba haciendo allá por el otoño del 2020
    [Componentes IRIS 2.ods]
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2021-02-01 Added Barometric sensor schematics Added I2C control board Added all the connectors of hte board
    [IRIS2_PCB_CPU.PrjPcb, IRIS2_PCB_CPU.SchDoc]
2021-02-01 First version of the schematics finished!!! Adding schematic libraries of many of the components Added the power stages of the schematics Added all the I2C components (Accelerometer, RTC, temperature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
    [Componentes IRIS 2.ods, IRIS2_PCB_CPU.PrjPcb, IRIS2_PCB_CPU.SchDoc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]
2021-02-09 Adding all the connector footprints and refrences for the BOM Adding the file with the PCB design Adding the step files with the picoblade connectors
    [IRIS2_PCB_CPU.PcbDoc, IRIS2_PCB_CPU.PrjPcb, IRIS2_PCB_CPU.SchDoc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]
2021-03-02 Cableada señal de alarma del monitor de tensión.
    Cableada señal de alarma del monitor de tensión y añadida al xlsx del pinout del micro
    [IRIS2_PCB_CPU.SchDoc, IRIS2_pinouts.xlsx]
2021-03-10 Añadida resistencia I2C al Excel y Creado su footprint
    Creado footprint para las resistencias del bus I2C. (Cuenta como una práctica con el altium, jeje)
    Cree una librería para componentes discretos (pasivos, más bien) Aitor, revisa si lo he hecho bien y me pondré a crear condensadores y después el resto.
    [Componentes IRIS 2.ods, IRIS2_PCB_CPU.PrjPcb]
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2021-03-20 Added Vin to the debug connector to be able to power up IRIS withtout using the internal batteries Updated pinout excel and added images of the pinouts, corrected the pinout of the Sunrise pins Updat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
    [IRIS2_pinouts.xlsx]
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2021-03-21 Finished uploading all the footprints and BOM data Started with the Board layout placement
    [IRIS2_PCB_CPU.PcbDoc, IRIS2_PCB_CPU.PrjPcb, IRIS2_PCB_CPU.SchDoc]
2021-03-21 Adding datasheets for the Battery holder Added resistor to protect the UARTs Continued routing. All items probably in the final position!!
    [BATT HOLDER_SMTU2032-LF.STEP, IRIS2_PCB_CPU.PcbDoc, IRIS2_PCB_CPU.PrjPcb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]
2021-03-21 Finished the first version of the Routing. Needs full review Added Step File of the PCB Added library of the Battery Holder
    [IRIS2_PCB_CPU.PcbDoc, IRIS2_PCB_CPU.PrjPcb, IRIS2_PCB_CPU.SchDoc]
2021-03-23 Empiezo con el FrontPlate y propuesta de DB15 debug en diagrama Bloques
    OJO, esta es una versión a medias. Mañana intentaré completar una actualización completa.
    [IRIS2_PCB_FrontPlate.PrjPcb, IRIS2_PCB_FrontPlate.SchDoc]
2021-03-24 FrontPlate actualizado y optimizado para 4 cámaras
    Diagrama de bloques del FrontPlate antualizado a 4 cámaras y optimizado a sólo 3 conectores al exterior.
    Carga + Debug en un DB15 Hembra + Sunrise signal en DB9 Hembra + Cargador en DB9 Macho
    [IRIS2_pinouts.xlsx]
2021-03-24 Esquema eléctrico del FrontPlate
    Avances en el esquema eléctrico. Falta poner manufacturer y reference de casi todos los componentes.
    [IRIS2_PCB_FrontPlate.PrjPcb, IRIS2_PCB_FrontPlate.SchDoc]
2021-04-01 Adding 4th camera to schematics Adding the library for the muxer of the UART and also its datasheet Adding the 20Mohm resistor to Chassis Modified the footprints of the Accelerometer and the pressure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
    [IRIS2_PCB_CPU.PrjPcb, IRIS2_PCB_CPU.SchDoc]
2021-04-01 Added the pinouts on the excel sheet for the MCU with the 4th camera and Muxer
    [IRIS2_pinouts.xlsx]
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2021-04-01 Adding the GERBERS for production! Added the STEP file for the mechanics team
    [20210401_IRIS2_PCB_CPU.step, 20210401_IRIS2_PCB_CPU_BOM.xlsx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]
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2021-04-05 Added bottom pour GND Added thermal relieves for through holes Changed the RGB led GPIOs in order to have PWM Updated BOM Moved to version v1.2
    [20210401_IRIS2_PCB_CPU_BOM.xlsx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]
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2021-04-14 Changed from fixed 5V output to adjustable, so we can feed the camera directly from the battery or any other things.
    [IRIS2_PCB_CPU.SchDoc]
2021-04-14 Changed the DC-DC to "Adjustable" and added a few of passive components in order to adapt it.
    [IRIS2_PCB_CPU.PcbDoc]
2021-04-16 Added DC-DC Resistor calculations Design is now V1.3 GERBERS updated BOM Updated Pick and Place files updated
    [20210415_IRIS2_PCB_CPU_BOM.xlsx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]
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2021-07-04 Updated V1.3 files, I2C address error and Pinout files
    Updated gitignore file
    Updated pinout with the error on the Power Enable of each camera
    Corrected the Barometric pressure I2C address
    [IRIS2_PCB_CPU.SchDoc, IRIS2_pinouts.xlsx]
2021-07-04 Updated the reference number for the UART Mux for the correct footprint
    [20210415_IRIS2_PCB_CPU_BOM.xlsx, IRIS2_PCB_CPU.SchDoc]
2021-07-04 Corrected footprint reference number
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2021-07-04 Pequeños cambios en circuito del opto
    Añadido condensador de 100nF y referencia del LED del circuito del opto
    [IRIS2_PCB_FrontPlate.SchDoc]
2021-07-05 Added picoblade and DB connector libraries
    Also added the initial file for PCB Layout
    [IRIS2_PCB_FrontPlate.PcbDoc, IRIS2_PCB_FrontPlate.PrjPcb, IRIS2_PCB_FrontPlate.SchDoc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]
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2021-07-06 Added all missing footprints, first realistic layout
    [Calculations.xlsx, IRIS2_PCB_FrontPlate.PcbDoc, IRIS2_PCB_FrontPlate.SchDoc]
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2021-07-10 Moved TPL optocoupler so it is not in the middle
    Also I added a missing reference
    [IRIS2_PCB_FrontPlate.PcbDoc, IRIS2_PCB_FrontPlate.SchDoc]
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2024-09-11 Move to the correct folder
    [191-009-113.STEP, 191-009-213.STEP, 191-015-223.STEP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]
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

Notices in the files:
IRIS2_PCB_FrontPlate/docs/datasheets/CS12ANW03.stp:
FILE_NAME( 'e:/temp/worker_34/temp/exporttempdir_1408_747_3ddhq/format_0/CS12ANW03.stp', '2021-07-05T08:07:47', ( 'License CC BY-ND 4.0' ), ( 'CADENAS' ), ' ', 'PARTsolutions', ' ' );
